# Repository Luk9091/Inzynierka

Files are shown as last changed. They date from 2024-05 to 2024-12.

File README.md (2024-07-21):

# Projekt Inżynierski
# Temat: Pojazdy autonomiczne z możliwością oceny aktualnej sytuacji na drodze

Opis:
Projekt zakłada zbudowanie autonomicznego pojazdu, który potrafiłby poruszać się po modelu miasta w sposób bezobsługowy. 
Układ rozpoznaje tor po którym się porusza. 
Samochód tworzy dwu-wymiarową mapę przestrzeni, a dla tak stworzonej mapy potrafi wyznaczyć optymalną trasę do punktu docelowego.

Powyższe repozytorium przedstawia *Projekt pracy inżynierskiej* będzie zbudowanie pojazdów autonomicznych, których zadaniem będzie poruszanie się po makiecie miasta.
Znajdowanie optymalnej trasy oraz możliwość rozwiązywania problemów dynamicznie pojawiających się problemów na wyznaczonej trasie.

# Uwagi do projektu!
Niezwykle ważne jest aby korzystać z określonej wersji FreeRTOS'a u mnie działa <u>**83da5fc95**</u>.

# Założenia budowy:
Projekt zakłada zbudowanie przynajmniej dwóch pojazdów. 
Każdy z pojazdów powinien spełniać poniższe założenia:
- [ ] Rozpoznawanie obrazu
    - [ ] Rozpoznawanie znaków
        - [ ] 1. Stop
        - [ ] 2. Zakręt
            - [ ] w prawo
            - [ ] w lewo
        - [ ] 3. Skrzyżowanie
        - [ ] 4. Ustąp pierwszeństwa
        - [ ] 5. Masz pierwszeństwo
- [ ] Tworzenie dynamicznej mapy 
    - [ ] Wyznaczanie trasy na mapie
    - [ ] Pomiar odległości
- [ ] Sterowanie silnikami
- [ ] Pomiary redundantne:
    - [ ] Pomiar temperatury
    - [ ] Pomiar azymutu
    - [ ] Pomiar wysokości nad poziomem morza
    - [ ] Pomiar przyspieszenia
    - [ ] Pomiar nachylenia

# Budowanie mapy
Mapa będzie przedstawiać, kwadratowe tile o ustalonych wymiarach `8b x 8b`

# Wymagania do zbudowania:
- C code lib:
    - RayLib

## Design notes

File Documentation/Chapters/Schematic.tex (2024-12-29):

\subsection{Opis układu}
    W rozdziale \ref{sec:building} opisano mechaniczną stronę projektu,
    natomiast poniżej przedstawiono elektroniczne aspekty pojazdu.
    Głównym odnośnikiem w tej sekcji jest schemat z rysunku \ref{schema:block}, prezentujący ogólny sposób połączenia całości.
    Moduły wybrane w tym układzie, zostały omówione we wstępie (rozdz. \ref{subsec:hardware}), dlatego też w tej sekcji skupiono się na zobrazowaniu relacji między poszczególnymi blokami.

    \subsection{Magistrala \texorpdfstring{$I^2C$}{I2C}}
        Protokół $I^2C$ (Inter-Integrated Circuit) jest szeregowym standardem komunikacyjnym między urządzeniem głównym (,,master'') a wieloma odbiornikami (,,slaves'').
        Transmisję rozpoczyna ,,master'', wysyłając adres podzespołu docelowego wraz z bitem $R/W$ ($Read / Write$), który informuje ,,slave'a'' czy ma odebrać, czy nadawać.
        Warstwę fizyczną realizują dwie linie Serial-Data (SDA) i Serial-Clock (SCL).
        Linia zegara odpowiada za synchronizację bitów, przekazywanych po ścieżce danych.
        Na rysunku \ref{fig:i2c_data_frame} przedstawiono przykładową ramkę tego protokołu.

        \begin{figure}[!ht]
            \centering
            
            \caption{Ramka protokołu $I^2C$}
            \label{fig:i2c_data_frame}
            Źródło: \href{https://en.wikipedia.org/wiki/I%C2%B2C}{en.wikipedia.org/wiki/$I^2C$}
        \end{figure}

        W tym projekcie, powyższy standard wykorzystywany jest do komunikacji z trzema rodzajami urządzeń:
        \begin{table}[!ht]
            \centering
            \caption{Lista urządzeń podłączonych za pomocą $I^2C$}
            \begin{tabular}{|c|c|c|c|}\hline
                Nazwa      & Identyfikator & Adres $I^2C$ & Liczba\\
                urządzenia &   układu      &(hexadecymalnie)& modłów\\\hline
                Akcelerometr & \centerY{2}{MPU6050} & \centerY{2}{0x68} & \centerY{2}{1} \\
                i żyroskop   &&&\\\hline
                Magnetometr & QMC5883L & 0x0D & 1 \\\hline
                ToF & VL53L0 & 0x29 & 3 \\\hline
            \end{tabular}
        \end{table}

        W przypadku każdego z układów adres domyślny ustalany jest przez producenta.
        Konsekwencją podłączenia kilku takich samych komponentów do magistrali, może być konflikt transmisji - błędy podczas odczytywania danych.
        Dlatego producenci czasem umożliwiają zmianę adresu urządzenia docelowego.
        Wymaga to jednak zastosowania dodatkowych linii $xShut$, pozwalających na sekwencyjne uruchamianie czujników, w celu nadania im nowego identyfikatora.
        Procedura ta została wykorzystana do połączenia modułów ToF.

    \subsection{Protokół \texorpdfstring{$SPI$}{SPI}}
        Trzy- lub cztero- przewodowy protokół transmisji szeregowej, pozwalający na szybkie przesyłanie dużej ilości danych.
        Bardzo często używany do komunikacji z pamięcią zewnętrzną lub innym procesorem.
        Dokładny opis tej magistrali znajduje się w dokumencie \citetitle{SPI} \cite{SPI}.
        W tym projekcie pamięć zewnętrzną $W25Q32JV$ podłączono do mikrokontrolera za pomocą czteroprzewodowej odmiany tego standardu.
        % \cite{SPI_memory}.

    \subsection{Mostek H i sterowanie silnikami}
        Sterowanie silnikami odbywa się poprzez specjalne układy, tak zwane mostki H, które pozwalają na przepływ znacznego prądu.
        Kontrolę każdego silnika zapewniają trzy przewody: \textit{enable, in~1, in~2}, a odpowiednie stany opisuje tabela poniżej (tab \ref{tab:motor_control_state}).

        \begin{table}[!ht]
            \centering
            \caption{Schemat sterowania silnikiem}
            \label{tab:motor_control_state}
            \begin{tabular}{|c|c|c|c|}\hline
                \multicolumn{3}{|c|}{Stan przewodu:} & \centerY{2}{Stan silnika} \\\cline{1-3}
                \textit{Enable} & \textit{In 1} & \textit{In 2} & \\\hline
                L & x & x & Stop\\\hline
                H & L & L & Stop\\\hline
                H & L & H & Obroty w prawo\\\hline
                H & H & L & Obroty w lewo\\\hline
                H & H & H & Stop\\\hline
            \end{tabular}
        \end{table}
        gdzie:
        \begin{itemize}
            \item x -- stan dowolny,
            \item L -- stan niski - zero logiczne,
            \item H -- stan wysoki - jedynka logiczna.
        \end{itemize}

        Jak widać obsługa napędu jest prostym zadaniem, a dodatkowo podłączając sygnał PWM do wejścia \textit{enable}, można regulować prędkość silnika.
        Co więcej, do obu motorów dołączone są enkodery, połączone z procesorem za pomocą czterech przewodów.
        Raspberry Pi Pico nie posiada sprzętowych liczników, jednak kontroler PWM pozwala na maskowanie głównego zegara zewnętrznymi sygnałami, na przykład zboczem sygnału z enkodera.
        Dzięki temu można zliczać impulsy, wysyłane przez te układy.
        Na wykresie poniżej (rys. \ref{plot:speed_in_duty}) przedstawiono zależność prędkości silnika od wypełnienia sterowania na linii \textit{enable}.

        \begin{figure}[!ht]
            \centering
            \begin{tikzpicture}
                \begin{axis}[
                    width = 0.6\textwidth,
                    grid = both,
                    grid style = dashed,
                    xlabel = Wypełnienie PWM {[\%]},
                    ylabel = Prędkość {$[\frac{mm}{s}]$},
                    legend pos = south east,
                    ytick = {20, 40, ..., 200}
                ]
                    \addplot table [x = duty, y = speedL, col sep = comma]{Measure/speed.csv};
                    % \addplot table [x = duty, y = speedR, col sep = comma]{Measure/speed.csv};
                    % \legend{Lewy silnik, Prawy silnik}
                \end{axis}
            \end{tikzpicture}
            \caption{Wykres prędkości silników w zależności od wypełnienia sygnału PWM}
            \label{plot:speed_in_duty}
            Pomiar przeprowadzony przy napięciu zasilania mostka $6V$ \\
            i stałej częstotliwości $f_{PWM} = 25kHz$
        \end{figure}

    % \subsection{Serwomechanizm}
    %     Na schemacie z rysunku \ref{schema:block} literą $S$ oznaczono serwomechanizm, kontrolujący przednią oś pojazdu.
    %     Sterowanie modułem odbywa się za pomocą kontroli wypełnienia sygnału w zakresie od $150\mu s$ do $950\mu s$, pracującego na częstotliwości $f_{PWM} = 50Hz$.

    % \subsection{Czujniki cofania}
    %     Oba czujniki zostały podłączone bezpośrednio do mikroprocesora.

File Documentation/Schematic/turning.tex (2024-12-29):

\begin{figure}[!ht]
    \centering
    \begin{tikzpicture}
        \draw
            (0, 0) node[draw, rectangle, rounded corners, fill = black, minimum width = 2cm, minimum height = 0.8cm, rotate = 30](frontL){}
            (0, -3) node[draw, rectangle, rounded corners, fill = black, minimum width = 2cm, minimum height = 0.8cm, rotate = 30](frontR){}

            (6, 0) node[draw, rectangle, rounded corners, fill = black, minimum width = 2cm, minimum height = 0.8cm](backL){}
            (6, -3) node[draw, rectangle, rounded corners, fill = black, minimum width = 2cm, minimum height = 0.8cm](backR){}

            (3, 0) node[above]{Zewnętrzna strona}
            (3,-3) node[below]{Wewnętrzna strona}
        ;

        \draw[Stealth-Stealth]
            (frontL) ++ (0, 1) --node[above]{$l$}++ (6, 0)
        ;
        \draw[dashed, gray]
            (frontL) --++(0, 1)
            (backL) --++(0, 1)
        ;

        \draw[color = red]
            (backL) -- ++ (0, -10) -- ++ (0, -1) coordinate(meet) --++ (0, -1)
            (frontL) -- (meet)
            (frontR) -- (meet)
        ;
        \draw
            (meet) ++ (0, 3) arc(90:127:3) node[above]{$\alpha$}
            (meet) ++ (0, 2) arc(90:147:1) node[above]{$\beta$}
        ;

        \draw[dotted]
            (backL) to[short, l=$\Delta r$] (backR)
            (backR) ++ (0, -2.5) node[right]{$r$}
        ;

        \draw[dashed]
            (frontL) ++ (0, 1) -- (0, -5)
            (0, -4) arc(90:180:-1)
            (0.5, -4.5) node[]{$\gamma$}
            (1.2, -4.25) node[rotate = -50]{$90 - \gamma$}
        ;
    \end{tikzpicture}
    \caption{Rysunek poglądowy skręcania}
    \label{draw:turning_car}
\end{figure}

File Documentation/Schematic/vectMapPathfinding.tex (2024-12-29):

\begin{figure}[!ht]
    \centering
    \begin{tikzpicture}
        \draw[]
            (0,  0) node[draw, circle, minimum width = 2cm, align = center](start){Nowa\\ścieżka}
            (-3, -2.5) node[draw, circle, minimum width = 2cm, align = center](instruction){Zmiana w\\instrukcje}
            (0, -6) node[draw, diamond, minimum width = 2cm, align = center](check){Czy występuje\\kolizja}
            (6, -6) node[minimum width = 2cm, align = center](noCollision){Powtarzaj dla wszystkich\\instrukcji i wektorów}
        ;

        \draw[-Stealth] (start) to[bend left] (instruction);
        \draw[-Stealth] (instruction) to[bend right] (check);
        \draw[-Stealth] (check) to[bend right] node[right]{Tak} (start);
        \draw[-Stealth] (check) to[bend right] node[below]{Nie} (noCollision);
        \draw[-Stealth] (noCollision) to[bend right] (check);
    \end{tikzpicture}
    \caption{Uproszczony algorytm do wyznaczania ścieżek na mapie wektorowej}
    \label{schematic:vectorMapPathfinding}
\end{figure}

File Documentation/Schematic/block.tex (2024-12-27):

    \useNormalLandscape
\section{Schemat elektroniczny}
    Na schemacie blokowym z rysunku \ref{schema:block} przedstawiono przepływ sygnałów sterujących wraz z połączeniem poszczególnych modułów.
\begin{figure}[!ht]
\centering
\vspace{1cm}
\begin{circuitikz}[fill = white]
    \draw[very thick]
        (0, 0) node[draw, rectangle, fill, minimum width = 4cm, minimum height = 4cm, align = center] (MCU) {Mikrokontroler\\\scriptsize{Raspberry PI Pico W}}

        (0, -5) node[draw, rectangle, fill, minimum width = 3cm, minimum height = 3cm, align = center] (HBridge){Mostek H}
        (HBridge.south) ++(1, 0) --++(0, -1) to[Telmech=M, n = LMotor] ++ (2, 0) --++ (0, 2) --++ (-2, 0)
        (HBridge.south) ++(-1, 0) --++(0, -1) to[Telmech=M,n = RMotor] ++ (-2, 0) --++ (0, 2) --++ (2, 0)

        (-10, 4) node[draw, rectangle, fill, minimum width = 2cm, minimum height = 2cm, align = center] (ToF1) {$\text{ToF}_1$}
        (-7, 4) node[draw, rectangle, fill, minimum width = 2cm, minimum height = 2cm, align = center] (ToF2) {$\text{ToF}_2$}
        (-4, 4) node[draw, rectangle, fill, minimum width = 2cm, minimum height = 2cm, align = center] (ToF3) {$\text{ToF}_3$}

        (-6, 0) node[draw, rectangle, fill, minimum width = 2cm, minimum height = 2cm, align = center] (MPU6050){MPU6050}
        (-6, -4) node[draw, rectangle, fill, minimum width = 2cm, minimum height = 2cm, align = center] (Magneto){Magnetometr}

        (6, -4) node[draw, rectangle, fill, minimum width = 2cm, minimum height = 2cm, align = center] (LIR){Czujnik\\cofania}
        (9, -4) node[draw, rectangle, fill, minimum width = 2cm, minimum height = 2cm, align = center] (RIR){Czujnik\\cofania}

        (6, 4) node[elmech=M, scale = 1.5](servo){S}
        (8, 0) node[draw, rectangle, fill, minimum width = 2cm, minimum height = 2cm, align = center] (memory) {Pamięć}
    ;

    \draw[]
        (MCU.east) to[bmultiwire = 4, a = SPI] (memory.west)
        (MCU.east) ++ (0, 1) to[short, i=PWM] ++ (4, 0) -| (servo.south)
        (MCU.east) ++ (0,-1) to[bmultiwire = 2] ++ (2, 0) --++ (0, -1) to[short, i<= Detect, -*]++ (2, 0) coordinate(IR_node)
            (IR_node)  to[multiwire=1] (LIR.north)
            (IR_node)  to[multiwire=1] ++ (3, 0)-| (RIR.north)

        (MCU.south) to[tmultiwire=6, i=\ ] (HBridge.north)

        (MCU.west) to[bmultiwire = 2, a = I2C, -*] ++ (-2, 0) coordinate(I2C)
        (I2C) -- (MPU6050.east)
        (I2C) |- (Magneto)

        (I2C) to[short, -*] ++ (0, 2) coordinate(I2C)
        (I2C) -- (ToF3.south)
        (I2C) to[short, -*]++ (-3, 0) coordinate(I2C) -- (ToF2.south)
        (I2C) -| (ToF1)

        (LMotor) to[crossing, i =\ ] ++ (0, 4) --++ (0, 0.5) to[bmultiwire, a = 2] ++ (-1, 0) --++ (0, 1)
        (RMotor) to[crossing, i =\ ] ++ (0, 4) --++ (0, 0.5) to[bmultiwire, l = 2] ++ ( 1, 0) --++ (0, 1)

        (ToF1.south) ++ (0.5, 0) -- ++ (0, -0.5)
            --++ (2, 0) to[crossing] ++ (1, 0)
            --++ (2, 0) to[crossing] ++ (1, 0)
            --++ (0, -1.25) to[tmultiwire, l = xShut, i<= \ ] ++ (1.5, 0)
        (ToF2.south) ++ (0.5, 0) to[short, -*] ++ (0, -0.5)
        (ToF3.south) ++ (0.5, 0) to[short, -*] ++ (0, -0.5)
    ;
\end{circuitikz}
\caption{Schemat blokowy przedstawiający przepływ sygnałów}
\label{schema:block}
\end{figure}
    \useportrait

\input{Chapters/Schematic.tex}

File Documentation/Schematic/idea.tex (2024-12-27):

    \useNormalLandscape
\section{Schemat ideowy}
\begin{figure}[!ht]
\centering
\vspace{1cm}
\begin{circuitikz}
    \draw
        % (0, -2) coordinate(GND_0)  node[right]{GND}

        (0,  0.0) coordinate(GPIO_0 ) node[right]{GPIO 0 }
        (0, -0.5) coordinate(GPIO_1 ) node[right]{GPIO 1 }
        (0, -1.0) coordinate(GND_0)   node[right]{GND}

        (0, -1.5) coordinate(GPIO_2 ) node[right]{GPIO 2 }
        (0, -2.0) coordinate(GPIO_3 ) node[right]{GPIO 3 }
        (0, -2.5) coordinate(GPIO_4 ) node[right]{GPIO 4 }
        (0, -3.0) coordinate(GPIO_5 ) node[right]{GPIO 5 }
        (0, -3.5) coordinate(GND_1)   node[right]{GND}

        (0, -4.0) coordinate(GPIO_6 ) node[right]{GPIO 6 }
        (0, -4.5) coordinate(GPIO_7 ) node[right]{GPIO 7 }
        (0, -5.0) coordinate(GPIO_8 ) node[right]{GPIO 8 }
        (0, -5.5) coordinate(GPIO_9 ) node[right]{GPIO 9 }
        (0, -6.0) coordinate(GND_2)   node[right]{GND}

        (0, -6.5) coordinate(GPIO_10) node[right]{GPIO 10}
        (0, -7.0) coordinate(GPIO_11) node[right]{GPIO 11}
        (0, -7.5) coordinate(GPIO_12) node[right]{GPIO 12}
        (0, -8.0) coordinate(GPIO_13) node[right]{GPIO 13}
        (0, -8.5) coordinate(GND_3)   node[right]{GND}

        (0, -9.0) coordinate(GPIO_14) node[right]{GPIO 14}
        (0, -9.5) coordinate(GPIO_15) node[right]{GPIO 15}

%  ##############################

        (5,  0.0) coordinate(VBUS)    node[left]{VBUS}
        (5, -0.5) coordinate(VSYS)    node[left]{VSYS}
        (5, -1.0) coordinate(GND_7)   node[left]{GND}

        (5, -1.5) coordinate(ADC)     node[left]{ADC REF}
        (5, -2.0) coordinate(3V3_EN)  node[left]{3V3 EN}
        (5, -2.5) coordinate(3V3)     node[left]{3V3}
        (5, -3.0) coordinate(GPIO_28) node[left]{GPIO 28}
        (5, -3.5) coordinate(GND_6)   node[left]{GND}

        (5, -4.0) coordinate(GPIO_27) node[left]{GPIO 27}
        (5, -4.5) coordinate(GPIO_26) node[left]{GPIO 26}
        (5, -5.0) coordinate(RUN)     node[left]{RUN}
        (5, -5.5) coordinate(GPIO_22) node[left]{GPIO 22}
        (5, -6.0) coordinate(GND_5)   node[left]{GND}

        (5, -6.5) coordinate(GPIO_21) node[left]{GPIO 21}
        (5, -7.0) coordinate(GPIO_20) node[left]{GPIO 20}
        (5, -7.5) coordinate(GPIO_19) node[left]{GPIO 19}
        (5, -8.0) coordinate(GPIO_18) node[left]{GPIO 18}
        (5, -8.5) coordinate(GND_4)   node[left]{GND}

        (5, -9.0) coordinate(GPIO_17) node[left]{GPIO 17}
        (5, -9.5) coordinate(GPIO_16) node[left]{GPIO 16}

        (0, 0.25) rectangle ++ (5, -10)
    ;
\end{circuitikz}
\end{figure}
    \useportrait

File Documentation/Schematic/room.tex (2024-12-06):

\begin{figure}
    \centering
    \begin{tikzpicture}[scale = 2]
        \draw
            (0, 0) rectangle (4.1, 2.7)
            (2, 1.7) --++ (2.1, 0)
            (2, 1.7) --++ (0, 1)
            (3.1, 0.2) --++(1, 0)
            (3.1, 0.2) --++(0,-0.2)
            
            (2.0, 1.5) node[draw, circle, minimum width = 0.5cm, fill = red]{}
            (3.1, 1.5) node[draw, circle, minimum width = 0.5cm, fill = red]{}
            (3.5, 1.0) node[draw, circle, minimum width = 0.5cm, fill = red]{}
        ;
        \draw[color=gray, dashed]
            (2.0, 1.5) -- (3.1, 1.5)
            (3.1, 1.5) arc(90:0:0.4)
        ;

        \draw[Stealth-Stealth] (2, 2) --node[above]{$2.0m$}++ (2.1, 0);
        \draw[Stealth-Stealth] (4.2, 1.7) --node[right]{$1.5m$}++ (0, -1.5);
        \draw[Stealth-Stealth] (3.1,-0.1) --node[below]{$1.0m$}++ (1, 0);
        \draw[Stealth-Stealth] (3.0, 0.2) --node[left]{$0.2m$}++ (0,-0.2);

    \end{tikzpicture}
    \caption{Schemat mapowanego pomieszczenia}
    \label{schematic:room}
\end{figure}

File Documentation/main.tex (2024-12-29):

\documentclass[12pt]{article}
\usepackage{anyfontsize}
\usepackage[a4paper, margin=2cm]{geometry}
\usepackage{polski}
\usepackage{tabto}
\usepackage{enumitem}
\usepackage{amsmath}
\usepackage{amssymb}
\usepackage{multirow}
\usepackage{multicol}
\usepackage{setspace}
\usepackage{listings}
\input{verticalPages.tex}

\setlength{\emergencystretch}{10pt}

\usepackage{tabularx}
\newcolumntype{C}{>{\centering\arraybackslash}X}
\newcolumntype{L}{>{\raggedleft\arraybackslash}X}
\newcolumntype{R}{>{\raggedright\arraybackslash}X}
\newcommand{\centerY}[2]{\multirow{#1}{*}{#2}}

\usepackage{wrapfig}
\usepackage{subcaption}

\usepackage{hyperref}
\hypersetup{
    colorlinks = true,
    urlcolor=blue,
    linkcolor= black,
    citecolor= blue
}

\usepackage{chngcntr}
\counterwithin{figure}{section}
\counterwithin{table}{section}
\numberwithin{equation}{section}

\usepackage{graphicx}
\graphicspath{{./Img/}}

\usepackage{csvsimple}
\usepackage{pgfplots}
\usepackage{pgfplotstable}
\pgfplotsset{compat= newest}

\usepackage{titlesec}
\titlelabel{\thetitle.\quad}
% \AddToHook{cmd/section/before}{\clearpage}

\usepackage[european, american currents, americanvoltages, RPvoltages, cute inductor]{circuitikz}
\usepackage{tikz}
\usetikzlibrary{shapes.geometric}
\ctikzset{
    logic ports=ieee,
    logic ports/scale=0.7,
}

\usepackage[polish]{babel}
\usepackage{csquotes}
\usepackage[sorting=none]{biblatex}
\bibliography{bibliography.bib}

\lstdefinestyle{asm}{
    belowcaptionskip=1\baselineskip,
    frame=L,
    xleftmargin=\parindent,
    showstringspaces=false,
    numbers=left,
    firstnumber=1,
    basicstyle=\footnotesize,
    basicstyle=\ttfamily,
    tabsize=4,
}

\usepackage{listings}
\lstset{
literate=%
    {ą}{{\k{a}}}1
    {Ą}{{\k{A}}}1
    {ć}{{\'c}}1
    {Ć}{{\'{C}}}1
    {ę}{{\k{e}}}1
    {Ę}{{\k{E}}}1
    {ł}{{\l{}}}1
    {Ł}{{\L{}}}1
    {ń}{{\'n}}1
    {Ń}{{\'N}}1
    {ó}{{\'o}}1
    {Ó}{{\'O}}1
    {ś}{{\'s}}1
    {Ś}{{\'S}}1
    {ż}{{\.z}}1
    {Ż}{{\.Z}}1
    {ź}{{\'z}}1
    {Ź}{{\'Z}}1
}

\title{
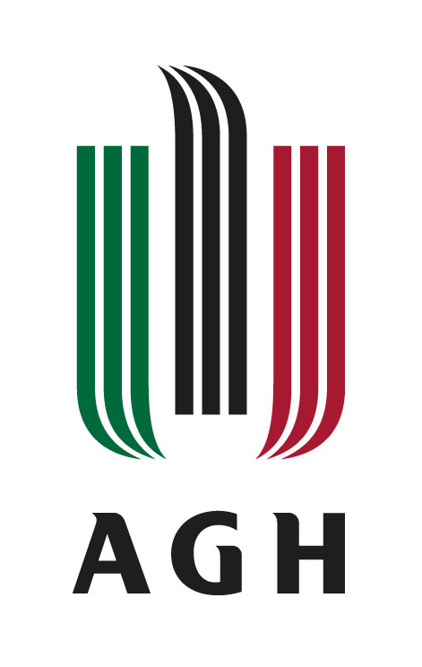
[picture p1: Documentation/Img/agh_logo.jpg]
    \\
    \textbf{Akademia Górniczo-Hutnicza w Krakowie}\\
    Wydział Informatyki, Elektroniki i  Telekomunikacji\\\vspace{2cm}
    \textbf{Praca inżynierska}\\
    Pojazd autonomiczny służący do pokonywania trasy z~przeszkodami\\\vspace{1cm}
    \small{An autonomous vehicle designed to navigate an obstacle course}
}
\author{
    \begin{tabularx}{\textwidth}{l l}
    Autor: &Łukasz Przystupa\\
    Kierunek studiów: & Elektronika\\
    Opiekun pracy: &dr inż. Agnieszka Dąbrowska-Boruch
    \end{tabularx}
}
\date{\vspace{2cm}\today}

\usepackage{titling}
\renewcommand\maketitlehooka{\null\mbox{}\vfill}
\renewcommand\maketitlehookd{\vfill\null}

\begin{document}
    \begin{titlepage}
        \maketitle
        \thispagestyle{empty}
        \newpage
        \
        \thispagestyle{empty}
    \end{titlepage}

    \pagenumbering{Roman}
        \include{shorts.tex}
        \tableofcontents
        \newpage
    \pagenumbering{arabic}
    % \input{Chapters/Abstract.tex}
    \include{Chapters/Introduction.tex}
    \include{Chapters/Building.tex}
    \include{Schematic/block.tex}
    \include{Chapters/Testing.tex}
    \include{Chapters/Issue.tex}
    \include{Chapters/Controll.tex}
    \include{Chapters/Map.tex}
\newpage
    \input{Chapters/Summary.tex}

    \vfill
    \begin{flushright}
        Łukasz Przystupa
    \end{flushright}

    \newpage
    \pagenumbering{gobble}
    \nocite{*}
    \printbibliography

    % \include{Schematic/idea}
    \listoffigures
    \listoftables
    % \lstlistoflistings

\end{document}

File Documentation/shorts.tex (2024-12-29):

\section*{Spis skrótów}
\addcontentsline{toc}{section}{Spis skrótów}
\begin{table*}[!ht]
    \begin{tabularx}{\textwidth}{|c|C|C|}\hline
        Skrót & Rozszerzenie\ & Opis\\\hline
        \centerY{2}{GPIO}       & \centerY{2}{General Purpose Input/Output} & Wyprowadzenia z układów scalonych do dowolnego wykorzystania\\\hline
        \centerY{2}{DIY}        & \centerY{2}{Do It Yourself} & Projekt do własnoręcznego wykonania\\\hline
        \centerY{2}{SSH}        & \centerY{2}{Secure Shell} & Protokół komunikacyjny, pozwalający na bezpieczne połączenie do serwera\\\hline
        \centerY{2}{HAL}        & \centerY{2}{Hardware Abstraction Layer} & Sposób porozumiewania się ze~sprzętem\\\hline
        \centerY{1}{RB Pi Pico} & \centerY{1}{Raspberry Pi Pico} & Mikrokontroler firmy Raspberry Pi\\\hline
        \centerY{3}{PWM}        & \centerY{3}{Pulse Wave Modulation} & Rodzaj modulacji cyfrowych pozwalający na regulację wypełnienia sygnału\\\hline
        \centerY{3}{ToF}        & \centerY{3}{Time of Flight} & Rodzaj czujników pomiaru odległości, polegający na pomiarze czasu przelotu wiązki światła\\\hline
        \centerY{2}{IR}         & \centerY{2}{Infrared} & Czujniki wykrywające promieniowanie podczerwone\\\hline
        \centerY{2}{CAD}        & \centerY{2}{Computer Aided Design} & Zestaw narzędzi do projektowania np.~modeli 3D\\\hline
        \centerY{3}{BMS}        & \centerY{3}{Battery Management System} & Układ elektroniczny, zabezpieczający akumulatory między innymi przed nadmiernym rozładowaniem\\\hline
        \centerY{4}{$I^2C$}     & \centerY{4}{Inter-Integrated Circuit} & Szeregowy protokół komunikacyjny, wykorzystywany do przekazywania danych między kilkoma czujnikami i~procesorem\\\hline
        \centerY{1}{$SDA$}      & \centerY{1}{Serial Data Line} & Linia danych w protokole $I^2C$\\\hline
        \centerY{1}{$SCL$}      & \centerY{1}{Serial Clock Line} & Linia zegara w protokole $I^2C$\\\hline
    \end{tabularx}
\end{table*}

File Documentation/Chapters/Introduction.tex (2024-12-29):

\section{Wstęp}
    Celem poniższej pracy jest skonstruowanie autonomicznego pojazdu, którego zadaniem będzie zbudowanie wirtualnej mapy terenu oraz samodzielne poruszanie się po nieznanym obszarze.
    Jednym z założeń projektu jest umożliwienie użytkownikowi kontroli nad pojazdem za pomocą dedykowanej aplikacji komputerowej.
    Dodatkowo, powyższa aplikacja będzie wyświetlać budowaną mapę w czasie rzeczywistym.
    Po wskazaniu punktu docelowego, zostanie zaproponowana optymalna trasa, po której pojazd będzie się poruszał.

    \subsection{Środowisko sprzętowe}
    \label{subsec:hardware}
        Współczesne pojazdy autonomiczne wyposażone są w jednostki obliczeniowe, które swoją konstrukcją przypominają pełnoprawne komputery z systemem operacyjnym.
        Ten projekt ma być modelem,  przedstawiającym działanie pojazdu autonomicznego, dlatego wykorzystanie pełnoprawnego komputera jest zbędne.

        \subsubsection{Mikrokontroler}
            Poniżej przedstawiono kilka najbardziej popularnym platform sprzętowych, które mogą stanowić bazę dla pojazdu.
            \begin{enumerate}
                \item Raspberry Pi -- komputer z systemem operacyjnym Linux, umożliwiający bezpośredni dostęp do modułów zewnętrznych z pomocą GPIO.
                Jest to najbardziej popularna platforma dla projektów DIY.
                Układ pozwala na niesamowitą elastyczność w pracy, między innymi na podłączenie się do układu za pośrednictwem SSH oraz pracę w języku Python.
                Jednak ze względu na swoją popularność, jest bardzo drogi i mało dostępny.
                Natomiast, jednym z założeń projektu jest działanie w czasie rzeczywistym, co przy wykorzystaniu systemu operacyjnego jest niemożliwe.
                \item Arduino -- najpopularniejsza platforma, której głównymi zaletami są: prostota framework'u oraz mnogość bibliotek dla każdego układu.
                Niestety, płytki te oparte są o 8-bitowe mikrokontrolery z rodziny AVR, co odbija się na ich prędkościach  (max 20MHz).
                Sam framework wykorzystywany jest na wielu różnych praformach, przez co w dłuższej perspektywie staje się nieintuicyjny.
                \item STM32 -- układy projektowane przez firmę STMicroelectronics. Są znacznie szybsze i~posiadają więcej pamięci od Arduino.
                Jednak ze względu na potrzebę wykorzystania biblioteki HAL, programowanie jest znacznie trudniejsze w porównaniu do innych układów.
                \item ESP32 -- 32-bitowy dwurdzeniowy procesor z wbudowanym modułem WiFi i Bluetooth.
                Jeden z najszybszych mikrokontrolerów dostępnych na rynku. Jest bardzo popularny w~projektach IoT (wytłumaczyć).
                Natywnie pracuje w systemie czasu rzeczywistego - FreeRTOS. Dzięki temu ma potencjał na bycie idealnym kandydatem do tego projektu.
                Jednak znikoma dokumentacja produktu sprawia, że praca z nim jest uciążliwa, przez co opracowanie optymalnego kodu jest znacząco utrudnione.
                \item Raspberry Pi Pico -- mikrokontroler od firmy Raspberry Pi, oparty na rdzeniach Cortex - tak samo jak STM32.
                Producent udostępnił wyjątkowo przystępny zestaw narzędzi programistycznych oraz przykładów użycia.
                Kolejną z zalet jest dobra dokumentacja tego procesora, która jest stale rozwijana.
                W 2022 roku, pojawiła się druga iteracja tej płytki Raspberry Pi Pico~W ze zintegrowanym modułem WiFi.
            \end{enumerate}
            Projekt jest możliwy do zrealizowania na wszystkich wymienionych powyżej platformach.
            Jednak ze względu na swoją przystępność, Raspberry Pi Pico jest najbardziej optymalnym wyborem.
            \begin{figure}[!ht]
                \centering
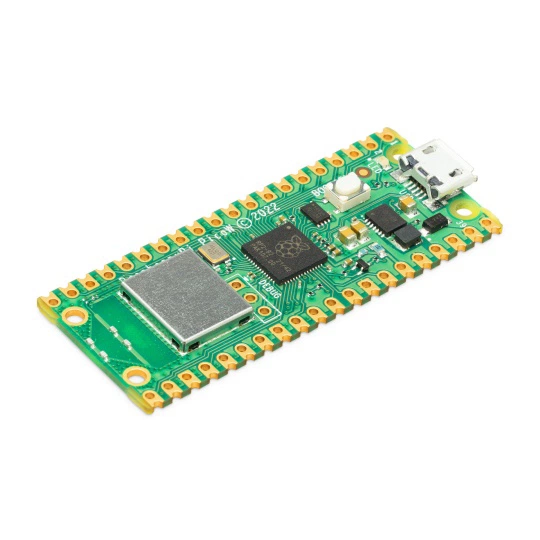
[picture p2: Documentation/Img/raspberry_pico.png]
                
                \caption{Raspberry Pi Pico}
                Źródło: \href{https://botland.com.pl/moduly-i-zestawy-do-raspberry-pi-pico/21574-raspberry-pi-pico-w-rp2040-arm-cortex-m0-cyw43439-wifi-5056561803173.html}{botland.com}

                % Źródło: https://botland.com.pl/silniki-dc-z-przekladnia-i-enkoderami/6287-silnik-z-przekladnia-sj01-120-1-6v-160rpm-enkoder-6959420910205.html
                % Źródło: https://botland.com.pl/serwa-typu-micro/20435-serwo-mg-90s-micro-180-stopni-metalowa-przekladnia-5904422380915.html
                \label{fig:raspberry_pico}
            \end{figure}

        \subsubsection{Sterowanie}
        \label{sec:engines}
            Podstawowym zadaniem pojazdów mechanicznych jest poruszanie się.
            Dlatego niezwykle istotne było wybranie odpowiedniego silnika napędowego.
            Na rynku konsumenckim istnieje jest wiele ich wariantów.
            Poniżej opisano możliwe rozwiązania oraz skrótowo omówiono ich wady i zalety:
            \begin{enumerate}
                \item Silniki krokowe -- niegdyś bardzo duże i drogie silniki, wymagające dodatkowych układów sterujących.
                Dziś jednak istnieją mniejsze, niskonapięciowe rozwiązania, które mogą być kontrolowaneZ bezpośrednio przez mikroprocesor.
                Niestety złożone sterowanie oraz niewielka prędkość maksymalna $v_{max} \approx 1 \frac{\text{obr.}}{s}$ sprawiają, że wykorzystanie ich w tym projekcie byłoby nieoptymalne.
                \item Serwomechanizmy $360^\circ$ -- silniki wraz z kontrolerem oraz przekładniami.
                Wbudowany układ pozwala na regulację prędkości z wysoką dokładnością.
                Nie ma jednak możliwości sprawdzenia, czy dwa moduły pracują z tą samą mocą.
                Może to prowadzić do wielu niepożądanych zachowań, jak na przykład trudności poruszaniem się w linii prostej.
                \item Serwomechanizmy $180^\circ$ -- ta odmiana pozwala na precyzyjne ustawienie pożądanego kąta.
                Układy te nie nadają się do napędzania pojazdów, gdyż ich zakres ruchu jest ograniczony do 180(stopni). Jednak, świetnie odnajdują się w sytuacjach, w których precyzja jest kluczowa.
                \item Silniki BLDC -- pozwalają osiągnąć bardzo wysokie prędkości.
                Niestety łączy się to z~niemałą ceną.
                Dodatkowo każdy silnik wymaga wyspecjalizowanych układu sterującego.
                \item Silniki DC -- urządzenia elektromechaniczne przetwarzające moc prądu stałego na energię mechaniczną.
                Pozwalają na regulację prędkości za pomocą PWM.
                Dodatkowo w sprzedaży dostępne są układy wyposazone w enkodery, pozwalające obliczyć średnią prędkość silnika, a w konsekwencji wyznaczyć różnicę w pracy między nimi.
            \end{enumerate}
            Układ napędowy został oparty na silnikach DC z zamontowanymi enkoderami.
            Dzięki czemu możliwy jest odczyt prędkości pojazdu, który pozwala na wprowadzanie korekty szybkości.
            Natomiast, do układu kierowniczego, najlepiej nada się serwomechanizm $180^\circ$, ze względu na możliwość precyzyjnego ustawienia kąta. Oba wybrane układy przedstawiono poniżej \ref{fig:engines}.
            \begin{figure}[!ht]
                \centering
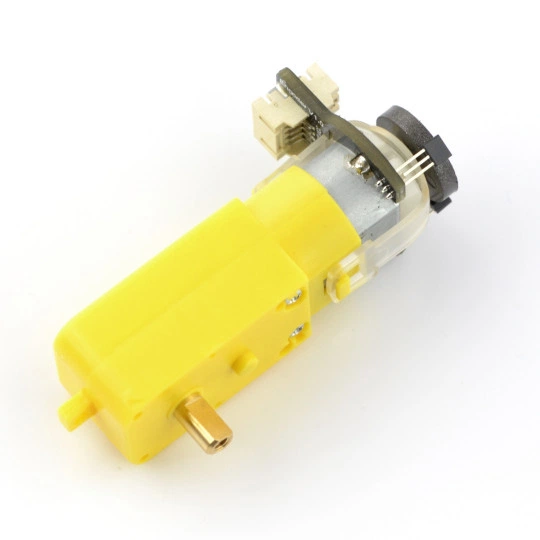
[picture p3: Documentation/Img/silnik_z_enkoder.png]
                
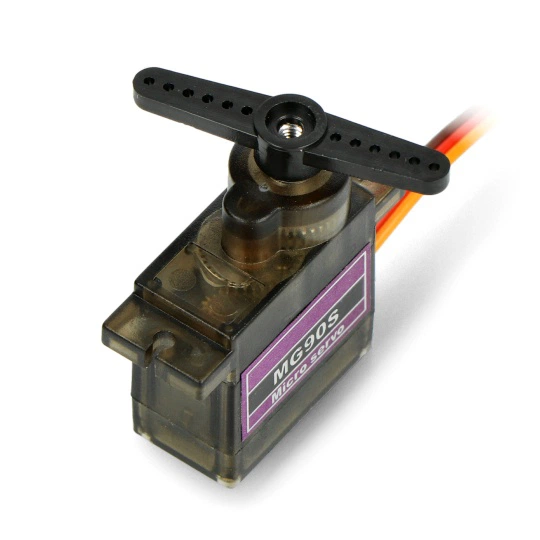
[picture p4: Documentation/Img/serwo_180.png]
                

                \caption{Silnik DC z enkoderem oraz serwomechanizmy $180^\circ$.}
                \footnotesize{Źródło: \href{https://botland.com.pl/}{botland.com}}
                % Źródło: https://botland.com.pl/silniki-dc-z-przekladnia-i-enkoderami/6287-silnik-z-przekladnia-sj01-120-1-6v-160rpm-enkoder-6959420910205.html
                % Źródło: https://botland.com.pl/serwa-typu-micro/20435-serwo-mg-90s-micro-180-stopni-metalowa-przekladnia-5904422380915.html
                \label{fig:engines}
            \end{figure}

        \subsubsection{Pomiar odległości}
            Praca pojazdów autonomicznych nie ogranicza się wyłącznie do sterowania silnikami.
            Urządzenia tego typu muszą być świadome swojego otoczenia.
            Zastosowanie odpowiednich czujników umożliwiających pomiar odległości jest niezbędne w celu zapewnienia bezkolizyjnej jazdy.
            % Autonomia pojazdu nie ogranicza się wyłącznie do sterowania silnikami.
            % Pojazd tego typu musi być świadomy swojego otoczenia.
            % Taką funkcjonalność mogą zapewnić czujniki służące do pomiaru odległości.
            % Ta funkcja wymaga wykorzystania czujników pozwalających na pomiar odległości.
            Poniżej przedstawiono listę różnych rodzajów czujników:
            \begin{enumerate}
                \item Czujniki ultradźwiękowe -- najpopularniejsze układy wykorzystywane do pomiaru odległości.
                Niewątpliwą zaletą jest prostota działania, jednak okupiona jest ona długim czasem wykonywania pomiarów.
                Co więcej uzyskane wartości obarczone są niepewnością, skutkującą znacznym odchyleniem od średniej.
                % Co więcej ich pomiary bywają niestabilne.
                \item Czujniki Time of Flight (ToF) -- wyspecjalizowane moduły o wysokiej dokładności, pozwalają na pomiary na znacznych odległościach.
                Zazwyczaj wymagają odpowiednich bibliotek dostarczonych przez producentów, co stanowi zarówno wadę jak i zaletę.
                Takie czujniki mogą pracować bardzo szybko jednak złożona, uniwersalna biblioteka spowalnia cały proces.
                \item Układy obiciowe IR -- obwody składające się z dwóch diod: emitera i odbiornika.
                Cechują się niewielkim zakresem pomiarowym (od $2cm$ do $20cm$) i znikomą dokładnością (pomiar zależy od koloru obiektu) oraz zauważalną strefą martwą.
                \item Lidar -- wyspecjalizowane układy, umożliwiające bardzo precyzyjny określenie odległości w pełnym zakresie $360^\circ$.
                Sprawia to, że jest jedną z najlepszych dostępnych opcji, jednak ceny takich układów są zaporowe.
                \item Radar -- niezwykle dokładne i kosztowne układy pomiarowe, pozwalające na nieporównywalną precyzję.
                Niestety ich rozmiar wymagany do tego projektu jest trudno dostępny na rynku konsumenckim.
                Co gorsza obowiązkowym staje się zastosowanie specjalnych procesorów sygnałowych, pozwalających na bieżąco przetwarzać dane z radarów.
            \end{enumerate}
            % Z wyżej przedstawionej listy, układami które sprawdzą się najlepiej w tym projekcie są czujniki typu ToF, zamontowane z przodu pojazdu.
            Z wyżej przedstawionej listy, w tym projekcie najlepiej sprawdzą się moduły ToF, zamontowane z przodu pojazdu.
            Dodatkowo ze względów bezpieczeństwa, z tyłu umieszczone zostały czujniki IR.
            Natomiast, nie są one wykorzystywane w charakterze urządzenia pomiarowego, tylko jako czujniki zbliżeniowe, umożliwiające wykrycie przeszkody i reakcję na niebezpieczeństwo.

    \subsection{Środowisko programistyczne}
        Następnym kluczowym wyborem jest środowisko programistyczne, w którym zostanie zbudowany projekt.
        % W ostatnich latach użytkownicy dostali bardzo dużo wolności w tej kwestii.
        W ostatnich latach powstało wiele narzędzi, pozwalających na dostosowanie całości do własnych potrzeb.
        Najpopularniejszymi narzędziami do programowania mikrokontrolerów są:
        \begin{enumerate}
            \item Eclipse -- kiedyś bardzo popularny program, posiadający olbrzymi zbiór rozszerzeń.
            Rozprowadzany na otwartej licencji, dlatego stanowi doskonałą bazę dla wielu bardziej zaawansowanych projektów.
            \item STM32 Cube -- środowisko przeznaczone głównie do pracy z modułami STM32, oparte na wyżej wymienionym Eclipse.
            \item Microchip Studio -- zbiór narzędzi wyspecjalizowanych do pracy z mikrokontrolerami z~rodziny AVR od firmy Microchip.
            \item Keil µVision -- program do programowania procesorów Cortex. Pomimo ograniczonej licencji jest bardzo popularny.
            \item Notepad++ -- bardziej zaawansowany notatnik, pozwalający na autouzupełnianie słów.
            Posiada też masę wtyczek, umożliwiających stworzenie z niego pełnoprawnego środowiska programistycznego, jednak w swojej pierwotnej wersji bardzo toporny w użyciu.
            \item Visual Studio Code (VS Code) -- uniwersalne narzędzie, mające ogrom dodatków, które dają możliwość przystosowania edytor w pełni pod własne wymagania.
            Sam program zbudowany jest na silniku przeglądarki internetowej, dzięki czemu może z powodzeniem zastąpić jej funkcje takie jak: przeglądarka PDF, a wbudowany tile menedżer pozwala układać całość w bardzo czytelny sposób.
        \end{enumerate}
        Projekt został, zbudowany z wykorzystaniem programu VS Code, ze względu na największą elastyczność oraz możliwość dostosowania go do własnych potrzeb.

    \subsection{Środowisko CAD}
        Zbudowanie pojazdu autonomicznego wymagało wymodelowania kilku niestandardowych części.
        W tym celu, zostało wykorzystane środowisko CAD, pozwalające na zaprojektowanie modelu 3D.
        Poniżej przedstawiono trzy najpopularniejsze programów do projektowania.
        \begin{enumerate}
            \item SolidWorks -- program stworzony przez firmę Dassault Systemes, który jest bardzo popularny w przemyśle.
            Pozwala na nieporównywalną precyzję a każda operacja wymaga zastanowienia przez co próg wejścia jest bardzo wysoki.
            \item Fusion 360 -- program stworzony przez firmę Autodesk, przeznaczony specjalnie do modelowania 3D.
            Posiada olbrzymie wsparcie dla drukarek 3D, a także dla obrabiarek CNC.
            Jest także niezwykle intuicyjny a próg wejścia jest bardzo niski.
            Jedyną wadą programu w wersji konsumenckiej, jest możliwość pracy wyłącznie w chmurze.
            \item FreeCAD -- darmowy program do projektowania modeli 3D, bardzo prosty w obsłudze, a~nauczenie się tego programu wymaga naprawdę niewielkiego wkładu pracy.
            Program jest stale rozwijany, a społeczność wokół niego ma możliwość rozbudowywania go o nowe funkcje.
            Niewątpliwą zaletą w porównaniu do innych programów jest możliwość uruchomienia go na każdym systemie operacyjnym.
        \end{enumerate}

        W projekcie został wykorzystany program FreeCAD, ze względu na swoją prostotę oraz możliwość uruchomienia na systemie Linux.

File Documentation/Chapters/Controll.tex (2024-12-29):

\section{Sterowanie pojazdem}
    Kierowanie pojazdem powinno odbywać się w sposób płynny i precyzyjny.
    W niniejszym rozdziale zostaną omówione algorytmy, odpowiedzialne za najbardziej podstawowe funkcje poruszania się, takie jak: jazda prosto, skręt oraz cofanie.

    \subsection{Jazda przez pewien odcinek}
    \label{subsec:jazda_przez_odcinek}
        Poprzednio (rozdz. \ref{sec:problemy_konstrukcyjne}) opisano problemy, jakie wystąpiły podczas budowy projektu.
        Ich rozwiązanie umożliwiło powtarzalność manewrów.
        Jednak dla precyzyjnego sterowania informacja o~tym, że pojazd porusza się po linii jest niewystarczająca.
        Obowiązkowym staje się poznanie odległości jaka została pokonana.

        Dystans przejechany przez samochód od momentu startu, możemy dość dokładnie obliczyć korzystając ze wzoru \eqref{eq:pulseToDistance}.
        \begin{gather}
            s = \frac{pulse \cdot 2\pi R}{N}
            \label{eq:pulseToDistance}
        \end{gather}
        gdzie:
        \begin{itemize}
            \item $s$ -- odległość pokonana,
            \item $pulse$ -- liczba impulsów z enkodera,
            \item $R$ -- promień koła,
            \item $N$ -- liczba impulsów na obrót.
        \end{itemize}

        Przekształcenie tego równania, pozwala na wyznaczenie ilości impulsów, które muszą być zliczone na danym dystansie.
        % Równanie to można także przekształcić w drugą stronę, aby wyznaczyć ile impulsów enkodera musi zostać zliczonych przez procesor, aby pojazd pokonał zadaną odległość.
        \begin{gather}
            \text{pulse} = \frac{s \cdot N}{2\pi R}
            \label{eq:distanceToPulse}
        \end{gather}

        Dla zbudowanego modelu promień koła jest równy $R = 25 mm$, a liczba impulsów zgodnie z dokumentacją to $N = 1920$.
        A więc dokładność pomiaru odległości wynosi około:
        \begin{gather}
            \Delta s \approx \pm0.1mm
        \end{gather}

        Wykorzystując formułę \eqref{eq:distanceToPulse}, procesor jest w stanie zatrzymać silniki, po przejechaniu określonej drogi.

    \subsection{Wyznaczanie zakrętów}
    \label{subsubsec:minamalny_promien}
        Opracowanie idealnie prostej trasy dla pojazdów nie zawsze jest możliwe.
        W trakcie jazdy samochód będzie skręcał wielokrotnie w każdym kierunku.
        Przedstawiony model posiada dwie osie, przez co nieosiągalne jest wykonanie tego manewru w miejscu.
        Natomiast może swobodnie poruszać się po okręgu o minimalnym promieniu.
        W tej sekcji zostanie opisany sposób jego wyznaczania w funkcji od kąta skrętu kół.

\newpage
        % \subsubsection{Minimalny promień skrętu}
            Wykorzystując rysunek \ref{draw:turning_car} oraz zależność \eqref{eq:turning_radius}, można obliczyć promień skrętu.
            Po podstawieniu wartości do wzoru, otrzymujemy:
            \begin{gather}
                r(\gamma = 90 \pm 30^\circ) = \left|\frac{155}{\tan(\pm 30^\circ)}\right| \approx 270mm
                \label{eq:theoretical_radius}
            \end{gather}

            Obliczoną wartość należy skonfrontować z rzeczywistością.
            W tym celu zaprezentowano inną metodę wyznaczenia tego samego promienia.
            Równanie \eqref{eq:turning_arc} pozwala na poznanie omawianego parametru na podstawie zakreślonego kąta i długości łuku.
            \begin{gather}
                s = 2\pi (r(\gamma) + \Delta r) \cdot \frac{\alpha}{360}
                \label{eq:turning_arc}
                % \\
                % \alpha = \frac{2\pi (r(\gamma + \Delta r))}{s \cdot 360}
            \end{gather}
            gdzie:
            \begin{itemize}
                \item $s$ -- długość łuku,
                \item $r(\gamma)$ -- promień skrętu,
                \item $\Delta r$ -- odległość między kołami,
                \item $\alpha$ -- zakreślony kąt.
            \end{itemize}

            Przekształcając powyższą zależność uzyskujemy:
            \begin{gather}
                r(\gamma) = \frac{s}{2\pi \cdot \frac{\alpha}{360}} - \Delta r
                \label{eq:turning_radius_with_arc}
            \end{gather}

            Odległość pokonana przez samochód jest dokładnie mierzona przez enkodery, a zakreślony kąt został wyznaczony przez wcześniej skalibrowany akcelerometr.
            Z tego względu można uznać, że obie wartości są precyzyjne.

            Przykładowo, dla ustawionego maksymalnego kąta skrętu kół $\gamma = (90 + 30)^\circ$ oraz długości łuku $s = 500mm$, zakreślony kąt wyniósł $\alpha = 60.0^\circ$.
            Podstawiając podane wyniki do równania \eqref{eq:turning_radius_with_arc}, otrzymujemy:
            \begin{gather}
                r = \frac{500mm}{2\pi \cdot \frac{60}{360}} - 125mm \approx 350mm
            \end{gather}

            Teoretyczny minimalny promień skrętu wychodzący z obliczeń \eqref{eq:theoretical_radius}, jest znacząco mniejszy od zmierzonego.
            Wynika to z nieidealności konstrukcji oraz zastosowania ,,względnie słabej jakości'' serwomechanizmu,
            co ogranicza maksymalny zakres skrętu do $\pm 24^\circ$.
            \begin{gather}
                r(\gamma = 90 + 24^\circ) = \left|\frac{155}{\tan(+ 24^\circ)}\right| \approx 350mm
            \end{gather}

            Jednak po uwzględnieniu zależności z sekcji \ref{subsec:nierownomiernosc_skretu} okazuje się, że różnica między teoretycznym a obliczonym kątem skrętu kół wynosi dokładnie wartość offsetu ($-6^\circ$).
            Dlatego też ograniczenie skrętu kół do $\pm 24^\circ$ nie jest potrzebne.
            W późniejszych obliczeniach kąt skrętu kół brany pod uwagę będzie w zakresie $\pm 30^\circ$.

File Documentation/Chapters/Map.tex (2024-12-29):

\section{Mapa i orientacja przestrzenna}
    Jednym z założeń projektu było napisanie dedykowanej aplikacji graficznej do sterowania pojazdem oraz prezentacji mapy.
    Na rysunku \ref{fig:app} przedstawiono interfejs tego programu, który składa z trzech części:
    \begin{figure}[!ht]
        \centering
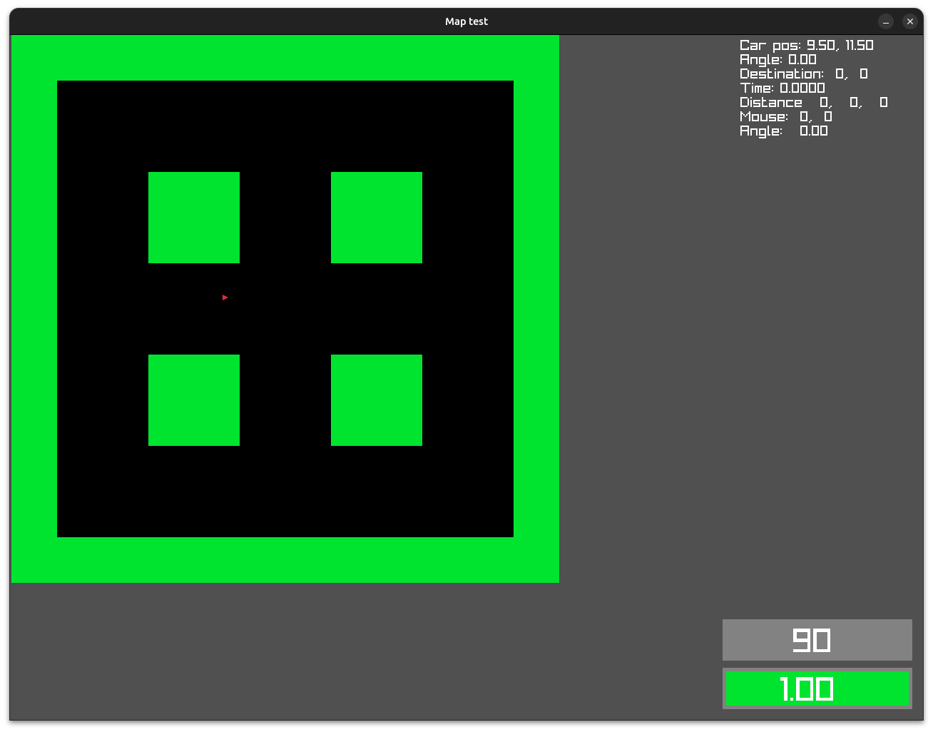
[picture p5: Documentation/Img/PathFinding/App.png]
        
        \caption{Interfejs aplikacji}
        \label{fig:app}
    \end{figure}
    \begin{enumerate}
        \item Mapa -- reprezentująca zbadany obszar oraz obecną pozycję pojazdu.
        \item Informacje -- w prawym górnym rogu wyświetlane są dodatkowe komunikaty, takie jak aktualne współrzędne samochodu, czy myszy.
        \item Ślizgacze -- w prawym dolnym rogu znajdują się dwa ślizgacze, górny umożliwia ustawienie kąta skrętu kół, a dolny pozwala na regulację prędkości pojazdu.
    \end{enumerate}

    \subsection{Wyszukiwanie ścieżek}
        W zamyśle program ma za zadanie jedynie wyświetlać mapę zbudowaną przez samochód, natomiast wszelkie obliczenia powinny zostać wykonane przez mikrokontroler.
        Jednak ze względu na dosyć skomplikowane przetwarzanie uzyskanych danych w celach testowych, to aplikacja posiada implementację przedstawionych algorytmów.

        Aby wytyczyć trasę, po której będzie poruszał się pojazd na narysowanej przestrzeni, należy wskazać punkt docelowy.
        W chwili kliknięcia rozpoczyna się złożony proces, który można podzielić na kilka podpunktów:
        \begin{enumerate}
            \item wyszukanie połączenia między dwoma miejscami,
            \item zamiana listy punktów na instrukcje,
            \item wygładzenie zakrętów.
        \end{enumerate}
        Wszystkie te elementy muszą działać niezawodnie, ponieważ błąd na którymkolwiek etapie, może mieć katastrofalne skutki.

        \subsubsection{Algorytm odnajdowania drogi}
        \label{subsec:algorytm_odnajdowania_ścieżek}
            Wyznaczanie optymalnej ścieżki, od wielu lat jest powszechnym problemem w informatyce i~robotyce.
            Istnieje mnóstwo artykułów, skupiających się na tej tematyce, a także ogrom gotowych rozwiązań.
            Do najpopularniejszych należą:
            \begin{itemize}
                \item algorytm A* (A star),
                \item algorytm Dijkstry,
                \item algorytm Bellmana-Forda.
            \end{itemize}

            Poniżej zaprezentowano wyniki pracy \citetitle{AnalizaAlgorytmówŚcieżek} \cite{AnalizaAlgorytmówŚcieżek}.
            \begin{figure}[!ht]
                \centering
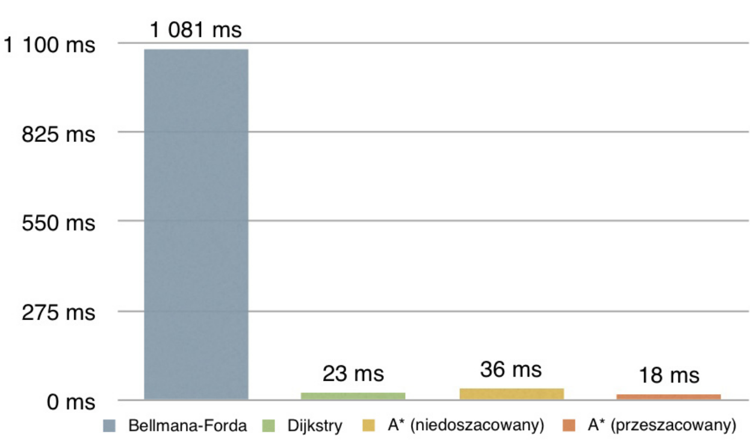
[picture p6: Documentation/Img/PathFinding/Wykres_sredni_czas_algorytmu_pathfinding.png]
                
                \caption{Wykres porównania średniego czasu wykonania algorytmów}
                Źródło:\cite{AnalizaAlgorytmówŚcieżek} \citetitle{AnalizaAlgorytmówŚcieżek}
                \label{fig:PathFindingTime}
            \end{figure}
            \begin{figure}[!ht]
                \centering
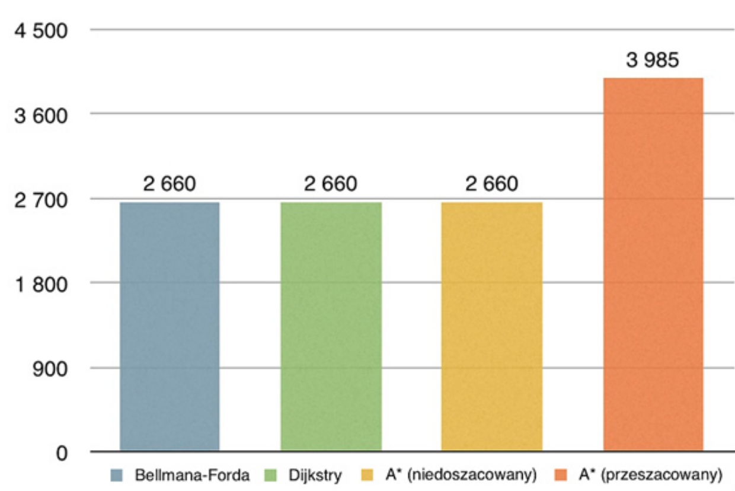
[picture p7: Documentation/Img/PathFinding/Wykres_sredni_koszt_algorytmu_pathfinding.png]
                
                \caption{Wykres porównania średniego kosztu znalezionych ścieżek}
                Źródło:\cite{AnalizaAlgorytmówŚcieżek} \citetitle{AnalizaAlgorytmówŚcieżek}
                \label{fig:PathFindingCost}
            \end{figure}

\newpage
            Na podstawie przedstawionego artykułu można wywnioskować, że najlepsze rozwiązanie to algorytm Dijkstry.
            Jego złożoność stanowi dodatkowy czynnik potwierdzający powyższe stwierdzenie.
            Jest on stosunkowo prosty w implementacji, a co więcej posiada niski koszt obliczeniowy.
            Dzięki temu wydaje się trafnym wyborem dla zastosowań w układach embedded.

    \subsection{Wygładzanie ścieżek}
    \label{subsec:wygładzanie_ścieżek}
        Rysunek \ref{fig:pathfinding_dikstra} prezentuje przykładową drogę, wyznaczoną przez algorytm Dijkstry,
        który zwraca najkrótsze połączenie między dwoma punkami, będące prostą.
        Jednak ze względu na ograniczenia konstrukcyjne wyrysowana trasa jest niemożliwa do pokonania przez robota.

        \begin{figure}[!ht]
            \centering
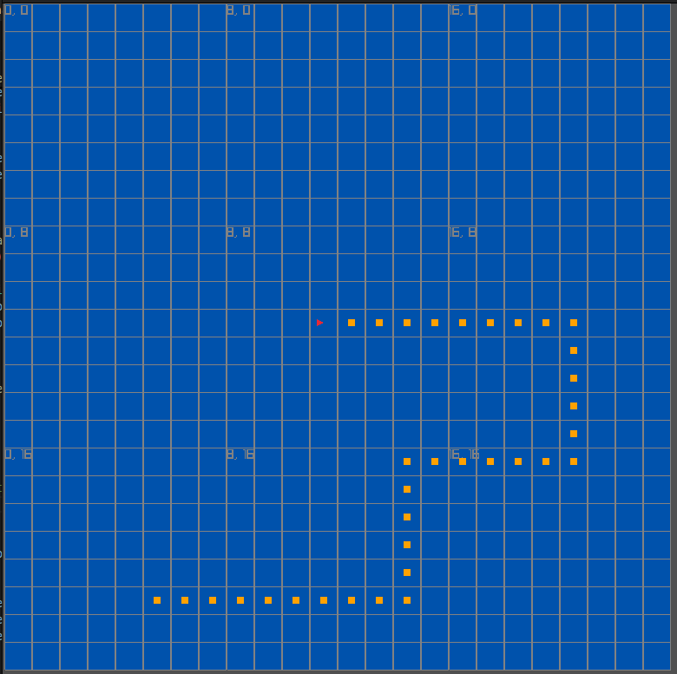
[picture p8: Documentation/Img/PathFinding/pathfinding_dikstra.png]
            
            \caption{Przykładowa ścieżka wyznaczona przez algorytm Dijkstry}
            \label{fig:pathfinding_dikstra}
        \end{figure}

        Zbudowany pojazd posiada tylko jedną oś skrętną, więc nie jest w stanie obrócić się w miejscu.
        Koniecznym jest zastosowanie algorytmu wygładzania.
        W artykule \citetitle{Simple_PathSmoothing} \cite{Simple_PathSmoothing} przedstawiona jest najprostsza możliwa metoda zaokrąglania krawędzi.
        Ów algorytm zakłada zapisywanie mapy w postaci listy punktów o niecałkowitych współrzędnych.
        Dzięki temu możliwe jest przesunięcie środka pojedynczej kratki w kierunku łuku skrętu.

        \begin{figure}[!ht]
            \centering
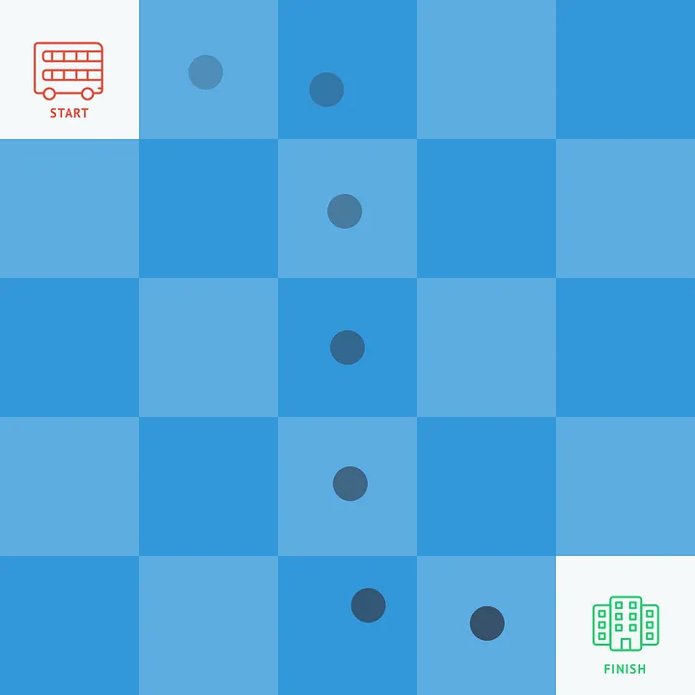
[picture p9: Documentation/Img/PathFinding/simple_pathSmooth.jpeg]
            
            \caption{Przykład wygładzania ścieżki na podstawie artykułu}
            \citetitle{Simple_PathSmoothing} \cite{Simple_PathSmoothing}
            \label{fig:simple_pathSmooth}
        \end{figure}

        Opisane rozwiązanie cechuje się niewielkim skomplikowaniem, jednak
        brak możliwości kontroli procesu, a także pocięcie drogi na pojedyncze punkty, między którymi pojazd będzie zatrzymywał się i ponownie ruszał, stanowią olbrzymi minus.
        Dodatkowo pojawia się problem przechowywania mapy w pamięci (sytuacja ta została dokładniej omówiona w rozdziale \ref{subsec:przechowywanie_mapy}).
        W związku z powyższym autor zdecydował się na użycie bardziej skomplikowanego algorytmu.

        Alternatywne metody wygładzenia ścieżek zostały ujęte w dokumentach: \citetitle{Compare_PathSmoothing} \cite{Compare_PathSmoothing} oraz \citetitle{Compare_PathSmoothing2} \cite{Compare_PathSmoothing2}.
        Obie prace przybliżają i~porównują różne sposoby dostosowywania trasy do umiejętności robota.
        Na rysunku \ref{fig:smoothingPath_res} przedstawiono ich wyniki:
        \begin{figure}[!ht]
            \centering
            \begin{minipage}{0.49\textwidth}
                \centering
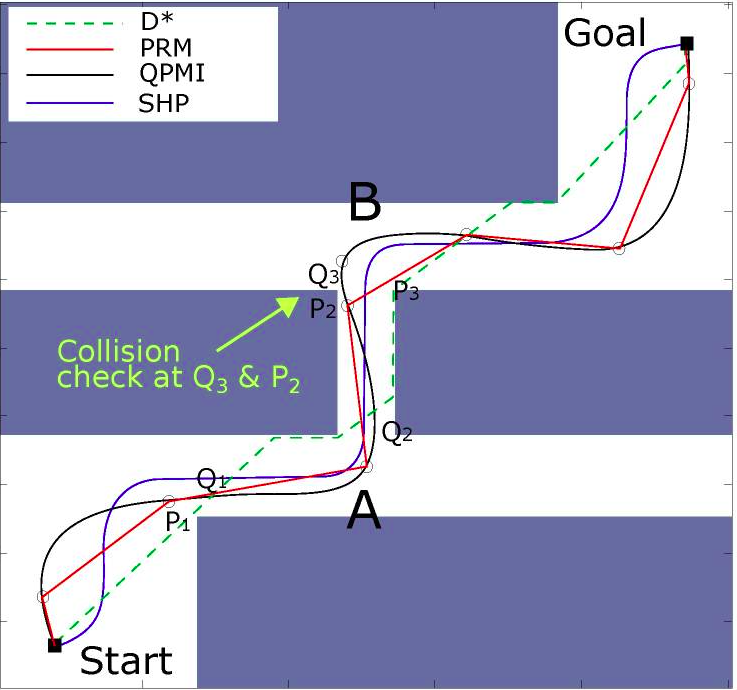
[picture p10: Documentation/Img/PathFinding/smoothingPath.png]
                
                Źródło: \cite{Compare_PathSmoothing} \citetitle{Compare_PathSmoothing}
            \end{minipage}
            \begin{minipage}{0.49\textwidth}
                \centering
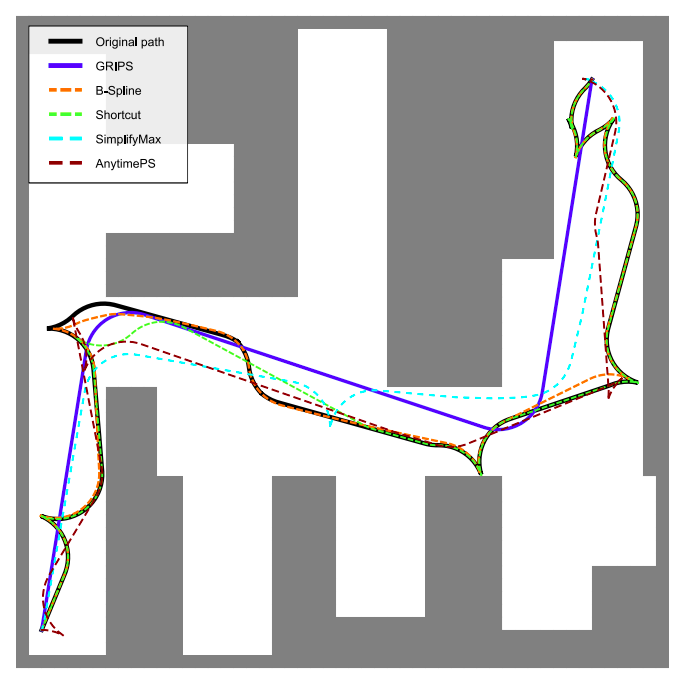
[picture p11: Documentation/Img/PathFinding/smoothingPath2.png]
                
                Źródło: \cite{Compare_PathSmoothing2} \citetitle{Compare_PathSmoothing2}
                \vspace{0.5cm}
            \end{minipage}
            \caption{Przedstawienie tras wygładzonych przez różne algorytmy}
            \label{fig:smoothingPath_res}
        \end{figure}

\newpage
        Ostatecznie spośród wszystkich wymienionych w artykułach metod został wybrany algorytm krzywych Dublina, ze względu na łatwą implementację oraz możliwość dostosowywania promienia skrętu.

\newpage
        \subsubsection{Opis algorytmu krzywych Dublina}
            Mechanizm wygładzania ścieżek za pomocą krzywych Dublina jest przeznaczony dla pojazdów o ograniczonej sterowności, przykładowo dla samochodów z tylko jedną osią skrętną.
            \begin{figure}[!ht]
                \centering
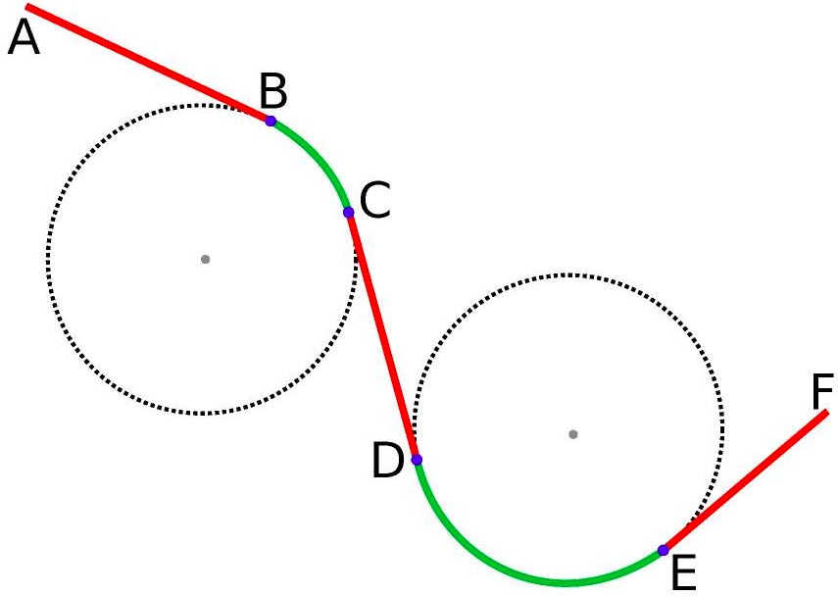
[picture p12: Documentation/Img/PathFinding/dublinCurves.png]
                
                \caption{Schemat trasy z okręgami o minimalnych promieniach}
                \label{fig:dublinCurves}
                Źródło: \cite{Compare_PathSmoothing} \citetitle{Compare_PathSmoothing}
            \end{figure}

        \begin{wrapfigure}[3]{R}{0.33\textwidth}
            \centering
            \vspace{-1cm}
            \begin{tikzpicture}
                \draw
                    (0,  0.0) node[draw, circle, minimum width = 0.5cm, align=center](A){1}
                    (0, -1.5) node[draw, circle, minimum width = 0.5cm, align=center](B){2}
                    (0, -3.0) node[draw, circle, minimum width = 0.5cm, align=center](C){3}
                    (0, -4.5) node[draw, circle, minimum width = 0.5cm, align=center](D){4}
                    (0, -6.0) node[draw, circle, minimum width = 0.5cm, align=center](E){5}
                    (0, -7.5) node[draw, circle, minimum width = 0.5cm, align=center](F){6}
                ;
                \draw[-Stealth] (A) -- (B);
                \draw[-Stealth] (B) -- (C);
                \draw[-Stealth] (C) -- (D);
                \draw[-Stealth] (D) -- (E);
                \draw[-Stealth] (E) -- (F);
                \draw[-Stealth] (F) to[bend right] (B);

            \end{tikzpicture}
            \caption{Implementacja algorytmu krzywych Dublina zastosowana w projekcie}
        \end{wrapfigure}

        Poniżej przedstawiono implementację algorytmu krzywych Dublina zastosowanego w projekcie.
        Opisana wersja jest nieoptymalną modyfikacją oryginału.

        \vspace{0.25cm}
        \begin{minipage}[l]{0.6\textwidth}
            \begin{enumerate}
                \item Zamiana punktów ścieżki na listę prostych o współrzędnych początkowych i końcowych.
                \item Ustalenie miejsca przecięcia się dwóch kolejnych linii.
                \item Wyznaczenie dwusiecznej kąta, tworzonego przez obie proste w punkcie przecięcia.
                \item Określenie kierunku, w którym samochód będzie poruszał się po zakręcie.
                \item Znalezienie na dwusiecznej środka okręgu, znajdującego się w przeciwnym kierunku do ruchu pojazdu.
                \item Obliczenie punktów styczności okręgu i obu prostych, które stanowią początek i koniec łuku.
            \end{enumerate}
        \end{minipage}
        \vspace{0.25cm}

        Pierwotne założenia mówią, że nie należy łączyć dwóch prostych łukiem, a zawsze o ile jest to możliwe ścieżka powinna zaczynać się i kończyć półokręgiem.
        Jednak w tym projekcie dużo łatwiej jest wyznaczyć łuk wiążący dwie proste, niż trzymać się optymalnej wersji algorytmu.
        Na rysunku \ref{fig:path_dublin} zaprezentowano rezultat wygładzania trasy.

        \begin{figure}[!ht]
            \centering
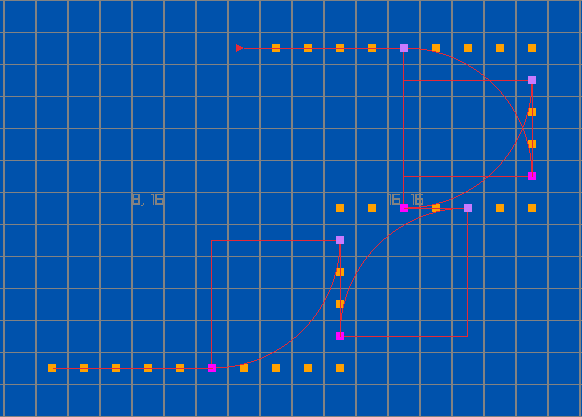
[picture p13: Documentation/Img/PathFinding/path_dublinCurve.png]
            
            \caption{Wyznaczona trasa z wygładzeniem}
            \label{fig:path_dublin}
        \end{figure}

    \subsection{Przechowywanie mapy}
    \label{subsec:przechowywanie_mapy}
        Przechowywanie mapy jest niezwykle złożonym zagadnieniem.
        W zależności od zastosowania oraz platformy, na której pracujemy, mogą istnieć różne sposoby jej przedstawienia.
        Zapisana na komputerze o teoretycznie nieograniczonej dostępnej pamięci, może być bardzo dokładna.
        Natomiast ten sam obraz analizowany przez mikrokontroler o niewielkich zasobach, musi zawierać uproszczenia.

        \subsubsection{Mapa jako tablica ścian}
            W wielu projektach mapa przechowywana jest w postaci dwuwymiarowej tablicy, w której poszczególne komórki odpowiadają określonym polom w labiryncie.
            Każda z nich zawiera informacje, w jakim kierunku można się poruszać.
            Przykład takiej budowy przedstawia artykuł \citetitle{maze_storage}\cite{maze_storage}.
            Na rysunku \ref{fig:mazeCellStorage} zilustrowano proponowane rozwiązanie.

            \begin{figure}[!ht]
                \centering
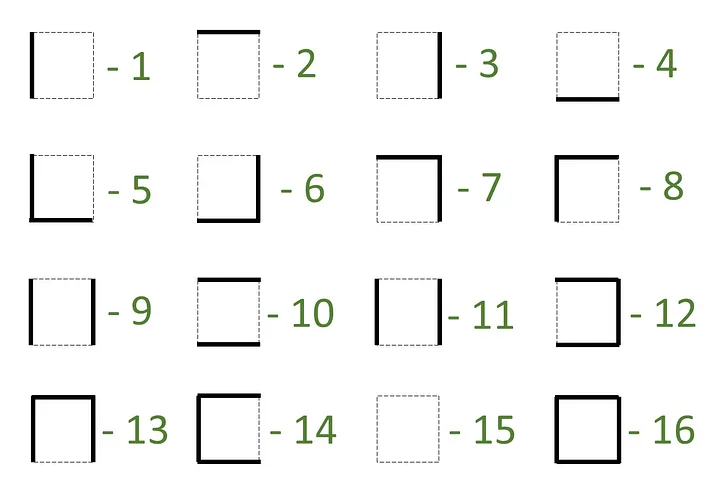
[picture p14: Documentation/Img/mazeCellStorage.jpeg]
                
                \caption{Przechowywanie komórek labiryntu z informacją o możliwości ruchu}
                Źródło: \citetitle{maze_storage}\cite{maze_storage}
                \label{fig:mazeCellStorage}
            \end{figure}

            Metoda ta jest bardzo skuteczna, kiedy znane są dokładne wymiary każdej części badanego obszaru,
            jednak przechowywanie mapy otwartej przestrzeni w podany sposób jest nieefektywne.
            Przykładowo, jeśli z kwadratu $A$ (patrz rys. \ref{fig:dim_issue}), nie da się jechać prosto to może oznaczać zarówno, że w miejscu połączenia z komórką $B$ jest ściana, jak i to, że pole $B$ jest całkowicie nieprzejezdne.
            W labiryncie, gdzie znaczenie mają krawędzie, prezentowane rozwiązanie jest optymalne.
            Jednak jeśli nie jesteśmy w stanie powiedzieć, czy wykrywamy cienką ściankę, czy też dużą przeszkodę, wtedy tracimy jednoznaczność.

            \begin{figure}[!ht]
                \centering
                \begin{tikzpicture}
                    \draw
                        (0, 0) -- (1, 0) -- (1, 1) -- (0, 1)
                        (0.5, 0.5) node{A}
                        (1, 0) rectangle (2, 1)
                        (1.5, 0.5) node[]{B}
                    ;
                \end{tikzpicture}
                \caption{Przykład niejednoznaczności wymiarów}
                \label{fig:dim_issue}
            \end{figure}

            Kolejną wadą takiej organizacji danych jest rozmiar pojedynczej komórki oraz czas potrzebny na przeanalizowanie wszystkich dostępnych opcji.
            Każdy kwadrat składa się z 4 bitów,
            co więcej łącząc poszczególne kratki ze sobą, okazuje się, że niektóre bity są nadmiarowe.
            Rozważmy sytuację: jeśli z punktu $A$ (rysunek \ref{fig:bit_issue}) nie możemy jechać do góry, to też, z punktu $C$ nie będzie możliwe przemieszczenie się w dół.
            Informacja dotycząca lokalizacji przeszkód musi zostać zapisana dla każdej komórki osobno.
            \begin{figure}[!ht]
                \centering
                \begin{tikzpicture}
                    \draw
                        (0, 0) -- (1, 0)
                        (1, 0) -- (2, 0) -- (2, 1) -- (1, 1)

                        (0.5, 0.5) node{A}
                        (0.5, 1.5) node{C}
                        (1.5, 0.5) node{D}
                    ;
                    \draw[dashed]
                        (0, 1) rectangle (1, 2)
                    ;
                    \draw[ultra thick, red]
                        (0, 1) -- (1, 1)
                    ;
                \end{tikzpicture}
                \caption{Przykład nadmiarowych informacji}
                \label{fig:bit_issue}
            \end{figure}\\
            Analogiczny problem występuje kiedy trasa jest przejezdna (połączenie między~$A$~i~$D$).

            Podsumowując, powyższa metoda przechowywania mapy jest użyteczna jedynie w przypadku labiryntów o jasno określonych zasadach.
            To rozwiązanie nie sprawdzi się do reprezentacji otwartej przestrzeni.
            Posiada zbyt wiele wad, aby można było próbować ją zastosować w~rzeczywistości.

        \subsubsection{Mapy wektorowe}
            Innym podejściem jest wykorzystanie wektorów.
            W takiej sytuacji teren rozważamy jako listę prostych figur geometrycznych, a nie jako zbiór komórek.
            Zostało to szczegółowo opisane w~artykule \citetitle{vector_map}\cite{vector_map}.

            \begin{figure}[!ht]
                \centering
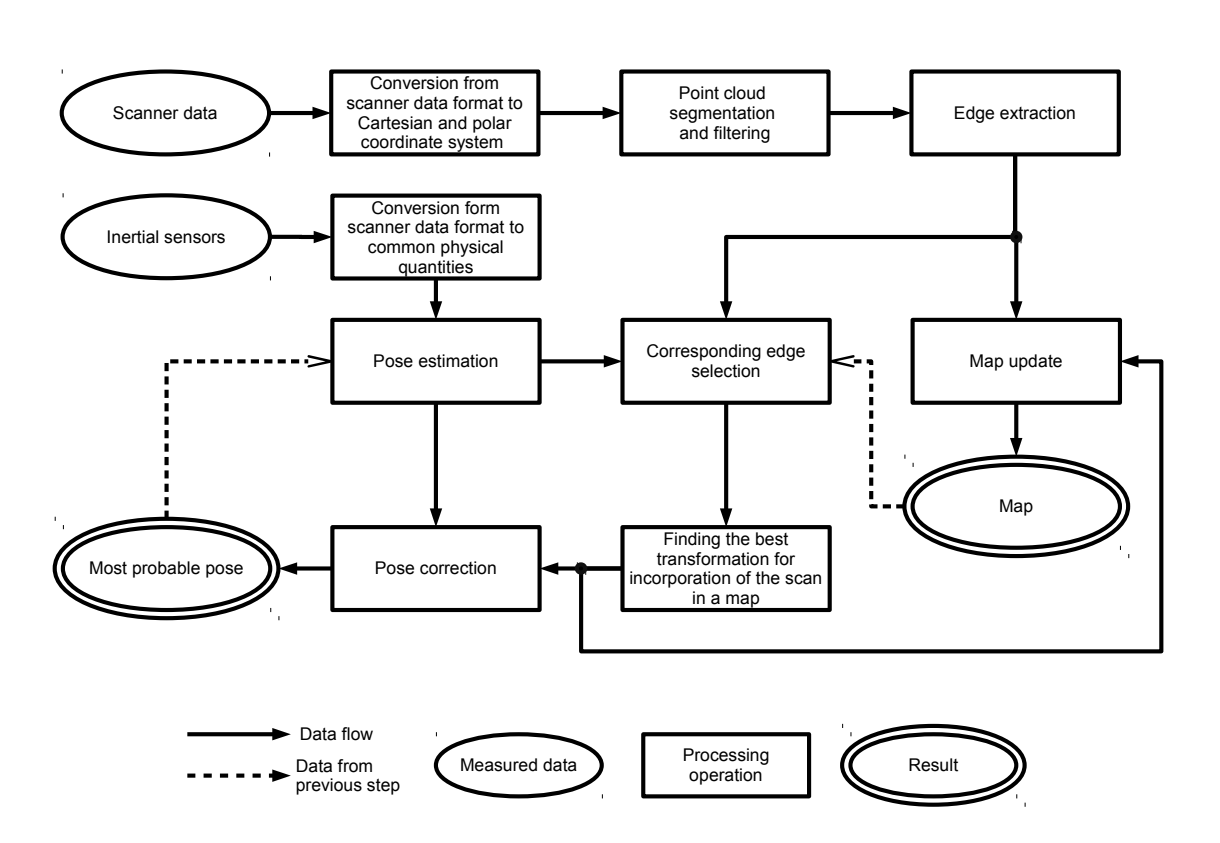
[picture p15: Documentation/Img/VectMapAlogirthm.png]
                
                \caption{Ogólny schemat przetwarzania punktów w mapę wektorową}
                Źródło: \citetitle{vector_map}\cite{vector_map}
                \label{fig:buildVectMap}
            \end{figure}

            Na ilustracji (rys. \ref{fig:buildVectMap}) zaprezentowano schemat algorytmu budowy takiej mapy, który jak można zauważyć, nie należy do najprostszych.
            Wymaga bardzo precyzyjnego próbkowania, nie ograniczającego się do minimalnej liczby punktów pomiarowych, a najlepsze rezultaty osiąga przy pełnym skanowaniu otoczenia.
            Co więcej, metoda ta wymusza nadmiarowość — każdy nowy obszar musi częściowo pokrywać się z wcześniej zmapowanym terenem.
            Obliczenie zmiany położenia oraz łączenie punktów w wektory jest czasochłonne, a wyznaczanie trasy na skomplikowanym planie trwa długo.
            Na schemacie \ref{schematic:vectorMapPathfinding} przedstawiono algorytm sprawdzania kolizji na ścieżce dla przestrzeni wektorowej.

            \input{Schematic/vectMapPathfinding.tex}

            Olbrzymią zaletą takich map jest możliwość nielimitowanego skalowania — w przeciwieństwie do obrazów rastrowych nie występuje w nich efekt "pikselizacji".
            Dodatkowo charakteryzują się one niewielkim rozmiarem przy zachowaniu dużej szczegółowości.

\newpage
        \subsubsection{Mapa rastrowa}
            Ostatnią zaproponowaną koncepcją jest mapa rastrowa.
            W tym przypadku dzielimy całą przestrzeń na równe kwadraty, a każdy z nich opisuje jeden z kilku możliwych stanów,
            na przykład:
            \begin{enumerate}
                \item pole nieznane,
                \item pole wolne,
                \item pole zajęte.
            \end{enumerate}

            Z drugiej strony wadą tej metody jest dyskretyzacja obszaru, która w zależności od stopnia zaawansowania może znacznie przekłamywać rzeczywistość.
            Przykładowo, dla jednego segmentu o wymiarach $100mm \times 100mm$ mniejsze obiekty mogą być albo całkowicie niewidoczne, albo przeszacowane.
            Dlatego niezwykle ważne jest, aby dostosować rozmiar pojedynczej kratki, zarówno do wielkości pojazdu, jak i całej przestrzeni.

            Następnym problemem jest pokaźna ilość pamięci potrzebna do przechowywania takiej powierzchni.
            Dla mapy o wymiarach $10m \times 10m$ i komórkach $100mm \times 100mm$ otrzymujemy:
            \begin{gather}
                V_{\text{size}} = \frac{10m}{100mm} \cdot \frac{10m}{100mm} \cdot 2bit = 20kbit
            \end{gather}

            Taką strukturę należało również optymalnie rozłożyć w pamięci, tak aby możliwy był szybki dostęp do grupy segmentów.
            Dla programu odnajdowania ścieżek nie jest istotne, czy pole jest nieznane, czy wolne, w obu przypadkach algorytm zachowa się tak samo.
            Z tego powodu można ograniczyć ilość bitów na kratkę do jednego.
            Dodatkowo możemy ułożyć poszczególne komórki w zbiory odpowiadające większym kwadratom.
            I tak:
            \begin{itemize}[label = -]
                \item osiem komórek w rzędzie to jeden bajt,
                \item osiem rzędów to jeden wiersz, a więc osiem bajtów,
            \end{itemize}
            dzięki czemu odczyt całego wiersza jest błyskawiczny.
            Jednocześnie procesor nie musi za każdym razem zwracać się do pamięci, jeśli chce odczytać informacje o następnej komórce.

            Ze względu na swoją prostotę i łatwość implementacji to właśnie ten sposób przechowywania mapy został zastosowany w projekcie.
            Dla tej metody policzono średni czas potrzebny na wyznaczenie ścieżki na drodze testowej przedstawionej na rysunku \ref{fig:pathFindingTime}, który wyniósł $t=100ms$.
%
            \begin{figure}
                \centering
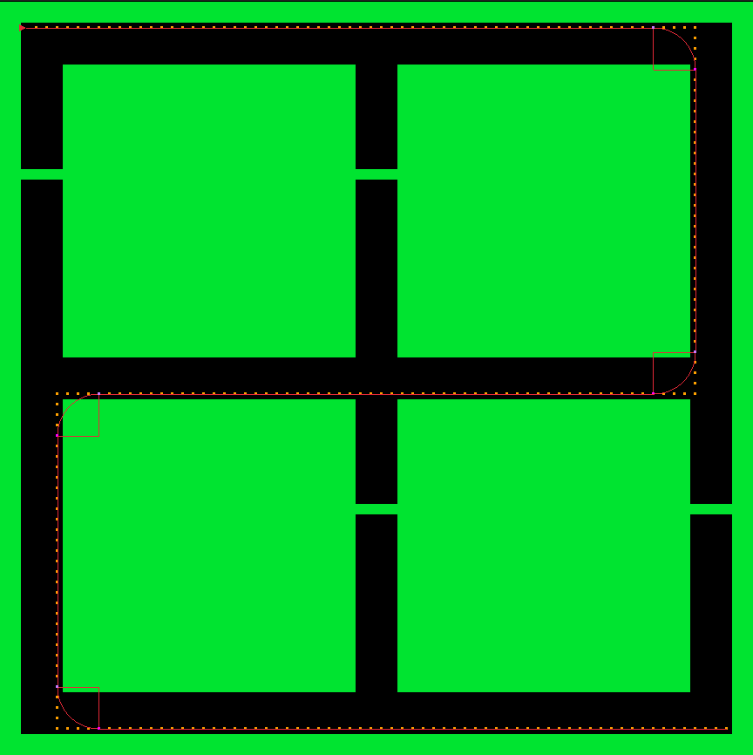
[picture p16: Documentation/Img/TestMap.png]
                
                \caption{Pomiar czasu wyznaczania ścieżki}
                Wymiary mapy: 72 komórki na 72 komórki
                \label{fig:pathFindingTime}
            \end{figure}
%
            Złożoność mapy ma niewielki wpływ na czas wyznaczenia trasy.
            Dla pustej mapy wartość ta oscylowała wokół $95ms$.
            Pozycja pojazdu oraz odległość od celu, niczego nie zmieniają.

    \subsection{Nanoszenie punktów pomiarowych}
        Jednym z podstawowych założeń była możliwość budowania mapy przez robota.
        W tym celu samochód musi mierzyć odległość w trakcie ruchu.
        Czujniki ToF zamontowane na przedzie pojazdu zostały ustawione w tryb ciągłej pracy z okresem $T ms$.
        Takie ustawienie pozwala na regularne odczytywanie dystansu, bez konieczności zajmowania procesora procedurą pomiarową.

        \subsubsection{Okres wykonywania pomiarów}
            Czas odebrania danych od pojedynczego modułu wynosi około $3ms$.
            Okres pomiarowy powinien być na tyle długi, aby pozwolić na odczytanie wszystkich czujników.
            Wartość $T$ musi być większa od $9ms$.
            Okres ten został ustawiony na $T = 100ms$.
            Dzięki temu pojazd jest w stanie w miarę na bieżąco reagować na zdarzenia, a jednocześnie mikrokontroler nie zajmuje się wyłącznie pomiarami.

        \subsection{Przykładowa mapa}
            Regularne próbkowanie oraz znajomość przebytej drogi między każdym z odcinków pozwala na dokładne określenie, w którym miejscu zostały wykonane poszczególne pomiary.
            Poniżej przedstawiono zrzut ekranu (rys. \ref{fig:buildMap}) z aplikacji z początkiem budowanej mapy o wymiarach $ 2.4m \times 2.4m$ i wielkości pojedynczej kratki $100mm \times 100mm$.

            \begin{figure}[!ht]
                \centering
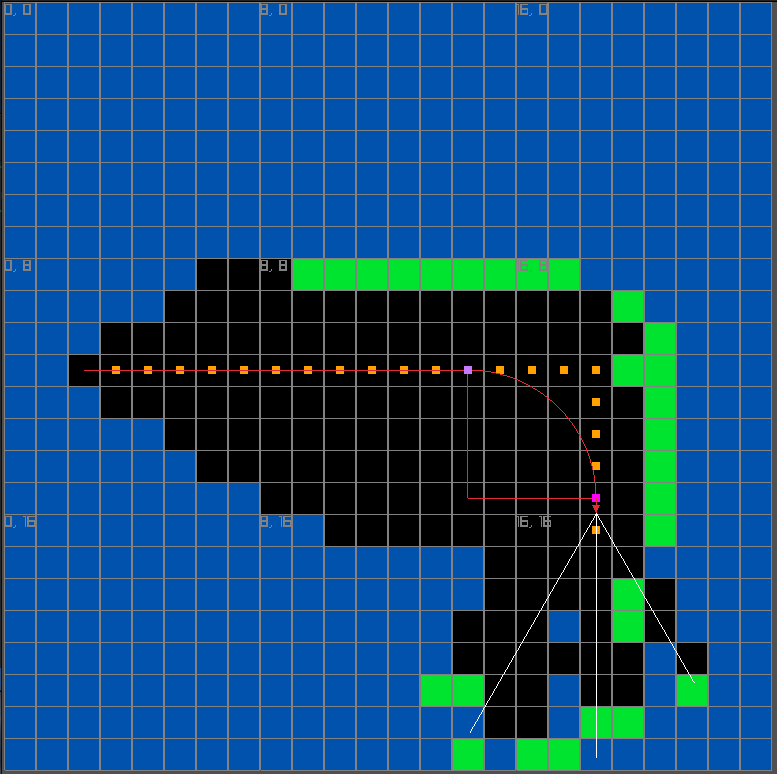
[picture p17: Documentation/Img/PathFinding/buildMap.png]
                
                \caption{Zbudowana mapa}
                \label{fig:buildMap}
            \end{figure}

            \input{Schematic/room.tex}

            Na schematycznym rysunku \ref{schematic:room} zaprezentowano rzut powierzchni, po której pojazd przemieszczał się.
            Czerwonymi kropkami oznaczono przybliżone miejsca zatrzymania się, a linia przerywana pokazuje pokonaną trasę.
            Jak widać, odzwierciedlenie mapy stworzonej przez robota jest dość dokładne względem rzeczywistego terenu.

            Zauważalne są pewne zniekształcenia, wynikające prawdopodobnie z niskiej rodzielczości mapy oraz nieidealność algorytmu rysującego.
            Pomimo tego wykonaną próbę można uznać za udaną.

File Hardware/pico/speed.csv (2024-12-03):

Continue
Speed: 13107
12630436 | 0.00 | 0.00
12732391 | 0.00 | 0.00
12834222 | 0.00 | 0.00
12936036 | 0.00 | 0.00
13037845 | 0.00 | 0.00
13139654 | 0.00 | 0.00
13241464 | 0.00 | 0.00
13343272 | 0.00 | 0.00
13445083 | 0.00 | 0.00
13546895 | 0.00 | 0.00
13648704 | 0.00 | 0.00
13750514 | 0.00 | 0.00
13852322 | 0.00 | 0.00
13954131 | 0.00 | 0.00
14055939 | 0.00 | 0.00
14157749 | 0.00 | 0.00
14259557 | 0.00 | 0.00
14361366 | 0.00 | 0.00
14463178 | 0.00 | 0.00
14564987 | 0.00 | 0.00
14666796 | 0.00 | 0.00
14768606 | 0.00 | 0.00
14870419 | 0.00 | 0.00
14972225 | 0.00 | 0.00
15074031 | 0.00 | 0.00
15175837 | 0.00 | 0.00
15277647 | 0.00 | 0.00
15379457 | 0.00 | 0.00
15481267 | 0.00 | 0.00
15583075 | 1.64 | 1.47
15684898 | 17.02 | 16.03
15786889 | 42.38 | 39.27
15888881 | 73.30 | 67.25
15990881 | 106.84 | 96.04
16092959 | 142.19 | 118.79
16195126 | 178.67 | 135.80
16297291 | 215.81 | 148.40
16399457 | 253.28 | 156.58
16501623 | 290.92 | 162.31
16603788 | 328.55 | 166.40
16705954 | 366.34 | 169.35
16808123 | 404.14 | 172.29
16910288 | 442.10 | 176.71
17012458 | 479.57 | 191.76
17114624 | 517.04 | 215.65
17216786 | 553.36 | 244.61
17318955 | 584.61 | 276.19
17421119 | 610.79 | 308.91
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

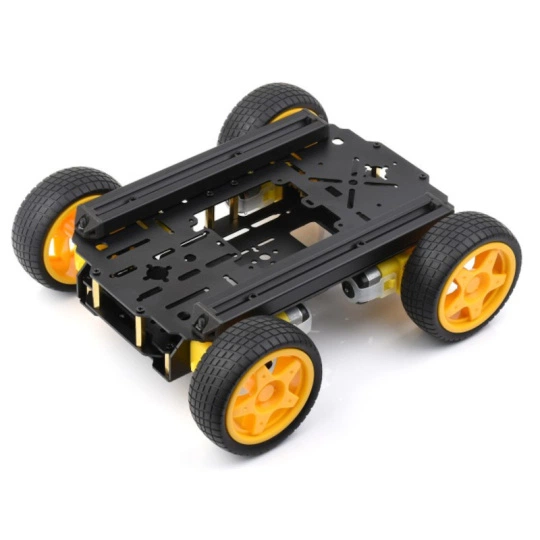
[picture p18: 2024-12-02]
Documentation/Img/chassis-waveshare-24419.webp

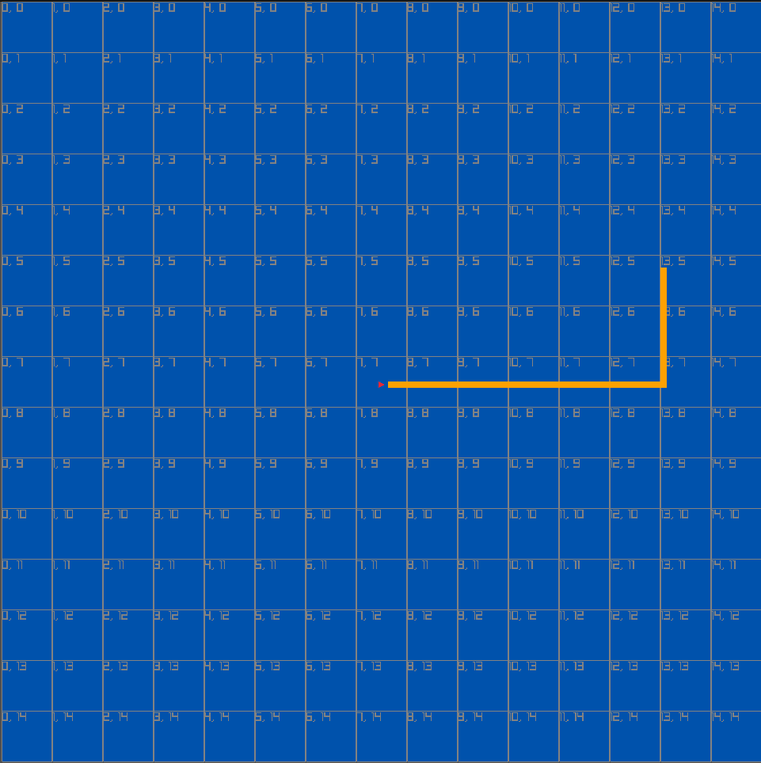
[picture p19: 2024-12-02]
Documentation/Img/PathFinding/Dikstra_pathFinding_rightTurn.png

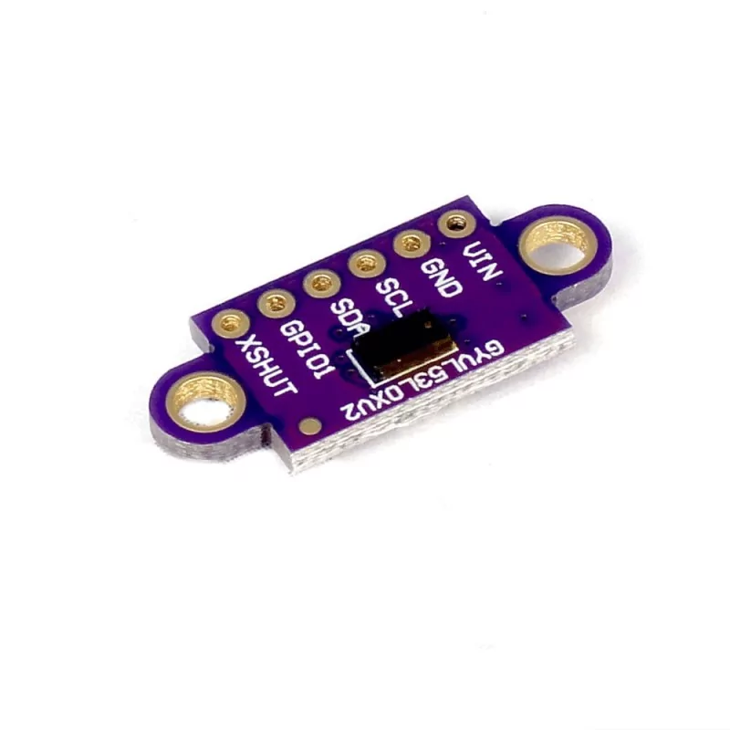
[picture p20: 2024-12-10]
Documentation/Img/tof.png

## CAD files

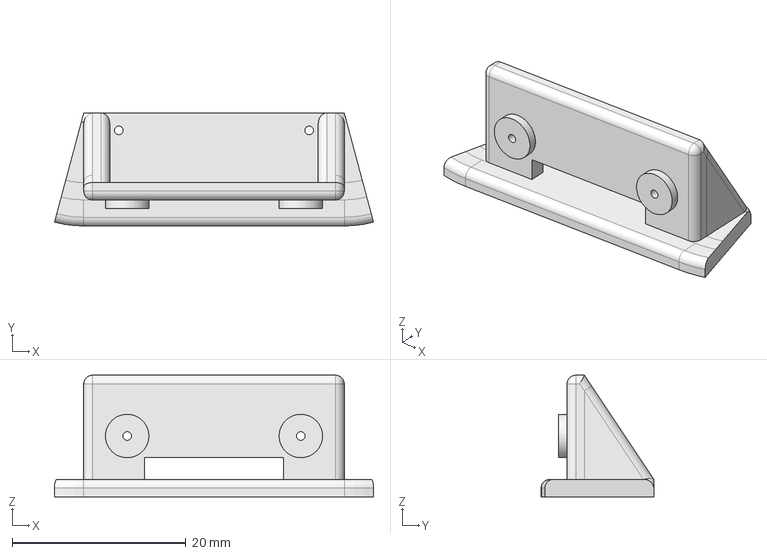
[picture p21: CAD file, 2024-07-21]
Modele/ToF_holder.FCStd
36.7 x 13.0 x 14.0 mm

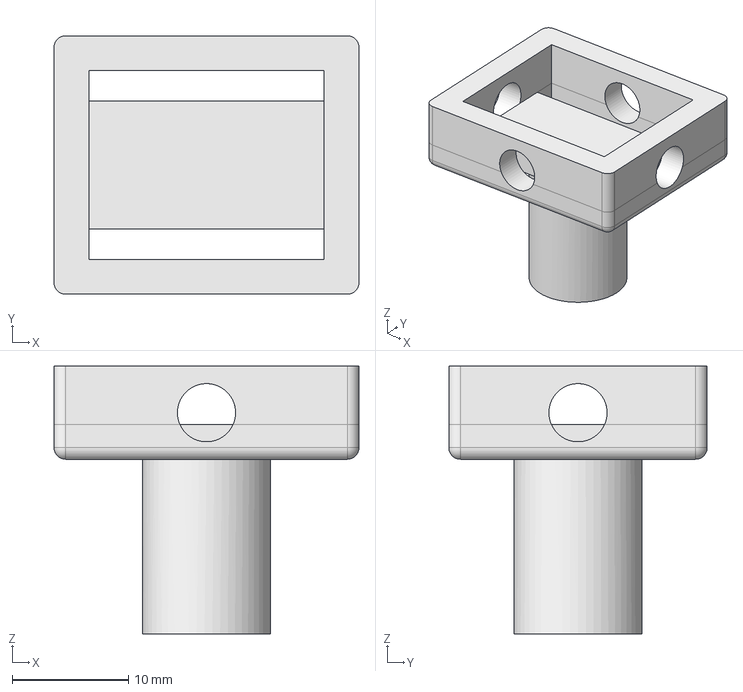
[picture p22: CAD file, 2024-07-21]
Modele/CalibrationHolder_MPU6050_longLeg.FCStd
26.2 x 22.2 x 23.0 mm

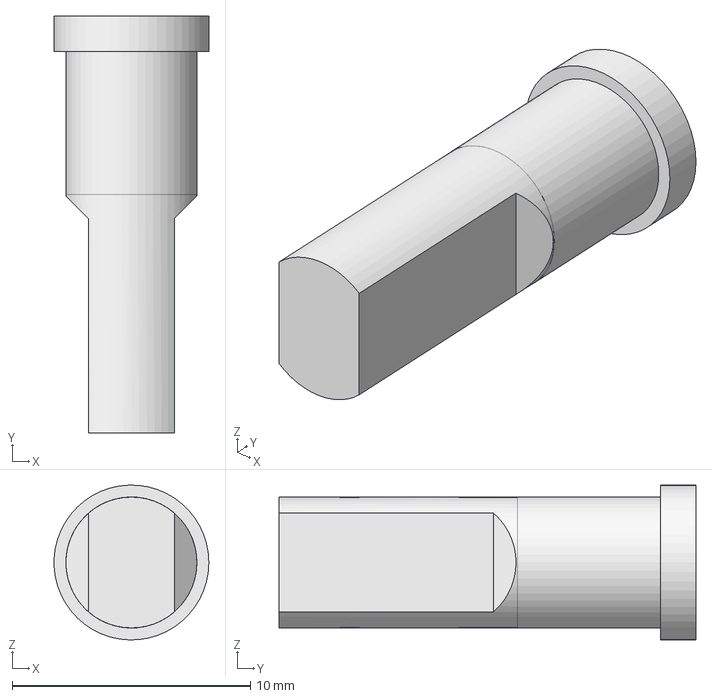
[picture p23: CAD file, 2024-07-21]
Modele/FrontWheelHolder.FCStd
6.49 x 17.5 x 6.50 mm

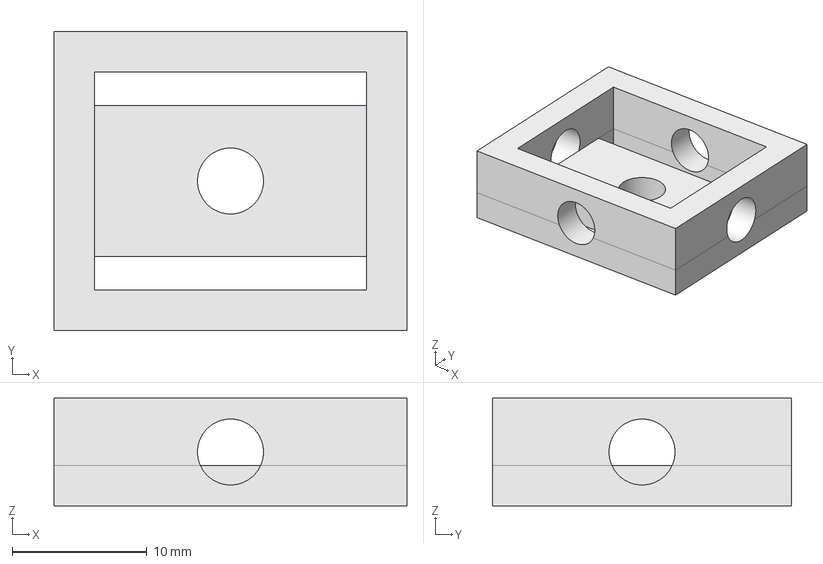
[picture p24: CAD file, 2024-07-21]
Modele/CalibrationHolder_MPU6050.FCStd
26.2 x 22.2 x 8.00 mm

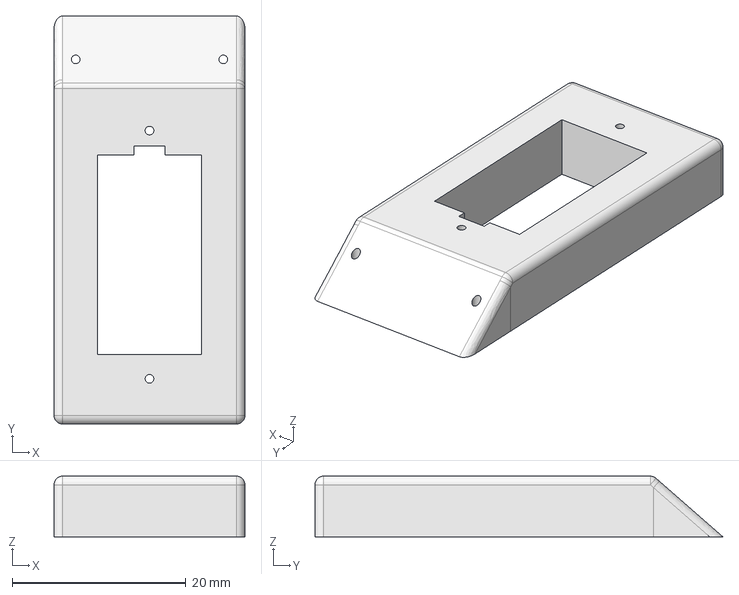
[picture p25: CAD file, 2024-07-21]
Modele/ServoHolder.FCStd
22.0 x 47.0 x 7.00 mm

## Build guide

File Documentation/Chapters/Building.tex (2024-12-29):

\section{Budowa pojazdu}
\label{sec:building}
    Inspiracją do stworzenia poniższego projektu były samochody autonomiczne, które najczęściej są pojazdami dwuosiowymi, z jedną osią skrętną i jedną napędową.
    Żadna z nich nie jest ze sobą połączona, co pozwoliło na niezależne sterowanie.
    W konstrukcji zostały użyte dwa silniki prądu stałego, wybrane w rozdziale \ref{sec:engines}, połączone bezpośrednio do tylnych kół.
    \subsection{Przednia oś}
    \label{subsec:drive_axis}
        Układ kierowniczy oparto na serwomechanizmie.
        Na rysunku \ref{fig:frontAxis_model} przedstawiono model tego elementu, zaprojektowanego przez autora.

        \begin{figure}[!ht]
            \centering
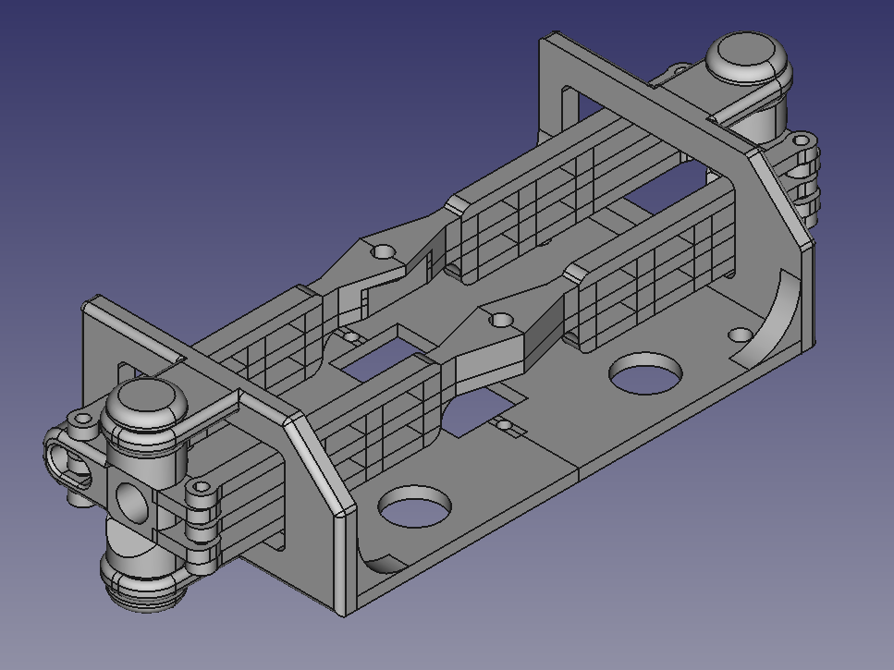
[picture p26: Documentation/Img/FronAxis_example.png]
            
            \caption{Przykładowy układ kierowniczy zaprojektowany w narzędziu FreeCAD}
            \label{fig:frontAxis_model}
        \end{figure}
        Mechanizm ten został rozplanowany w taki sposób, aby środek osi znajdował się w linii ze środkiem serwomechanizmu.
        Dzięki temu ustawiony kąt serwa, odpowiada kątowi skrętu kół.
        Natomiast dużą wadą takiego połączenia jest możliwość jego uszkodzenia, po przekroczeniu maksymalnego zakresu ruchu.

    \subsection{Rama pojazdu}
    Do budowy podwozia została wykorzystana gotowa rama, z poniższego zdjęcia (rys. \ref{fig:test_chassis}), produkowana przez firmę Waveshare.
\clearpage
    \begin{figure}[!ht]
        \centering
        
        \caption{Rama Waveshare 24419}
        Źródło: \href{https://www.waveshare.com/robot-chassis.htm?sku=24419}{waveshare.com}
        \label{fig:test_chassis}
    \end{figure}

    Aby spełnić założenia projektowe, przednia oś konstrukcji została wymieniona na wyżej opisaną (rozdział \ref{subsec:drive_axis}).
    Dodatkowo zmieniono sposób montażu silników, które zamontowano odwrotnie do zaleceń producenta (rys. \ref{fig:motors}), a także zrezygnowano z ,,gumek", odpowiadających za amortyzację.

    \input{Schematic/motors.tex}

    \subsection{Pomiar odległości}
        Współczesne pojazdy autonomiczne wykorzystują układy LIDAR, które pozwalają mierzyć w~pełnym zakresie $360^\circ$.
        Jednak w wielu sytuacjach taki pomiar mija się z celem, gdyż znaczna część próbek zostaje odrzucona.
        Same LIDARy zaś są bardzo drogimi urządzeniami, często z~niestandardowym sposobem komunikacji (np. za pomocą UART).
        Z tego względu autor zdecydował się na zastosowanie tańszych czujników ToF.
        Trzy takie moduły umieszczono z przodu samochodu, z krokiem co $30^\circ$.
        Na rysunku \ref{fig:ToF_holder} zaprezentowano model mocowania wyżej wymienionych elementów.

        \begin{figure}[!ht]
            \centering
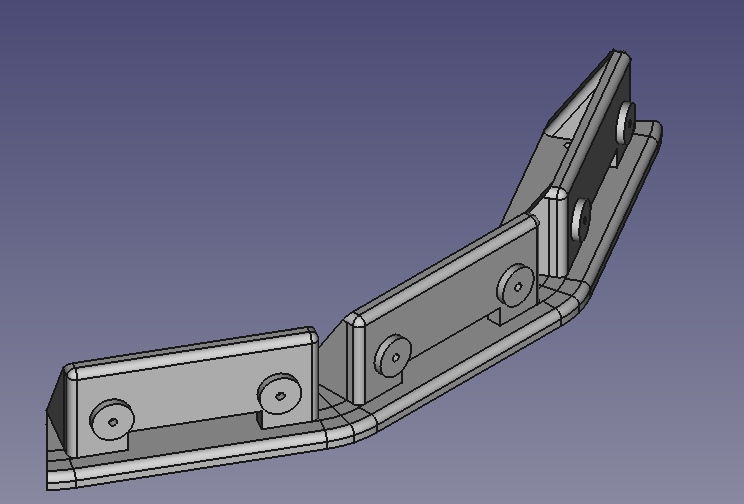
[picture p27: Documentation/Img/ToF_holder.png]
            
            \caption{Mocowanie czujników ToF}
            \label{fig:ToF_holder}
        \end{figure}

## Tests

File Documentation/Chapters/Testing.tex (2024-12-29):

\section{Środowisko testowe}
\label{sec:testing}
    Podczas budowy dowolnego systemu, niezwykle ważne jest testowanie elementów składowych.
    Połączone moduły również wymagają sprawdzenia ich współpracy.
    W informatyce kontrolę oprogramowania zapewniają testy jednostkowe, które weryfikują działanie poszczególnych algorytmów i programów.
    Natomiast w przypadku prac nad sprzętem niezbędne jest zbudowanie odpowiedniego środowiska, pozwalającego na testowanie każdego elementu osobno oraz łącznie poszczególnych podzespołów w bloki funkcjonalne.
    Dlatego wykonanie fizyczne należy podzielić na kilka etapów, opisanych poniżej:
    \begin{enumerate}
        \item Budowa prototypu na płytce stykowej.
        \item Złożenie ramy pojazdu z elektroniką umieszczoną na płytce stykowej wraz z doprowadzonym zewnętrznym zasilaniem.
        \item Sprawdzenie działania pojazdu z płytką stykową zasilaną bateryjnie.
        \item Wykonanie płytki prototypowej z połączeniami wszystkich elementów na stałe ponownie z zewnętrznym zasilaniem.
        \item Sprawdzenie działania prototypu pojazdu z zasilaniem akumulatorowym.
    \end{enumerate}
    Każdy z wymienionych kroków charakteryzował się innym rodzajem testów oraz własnymi problemami.
    Zakończenie jednej fazy i przejście do następnej było możliwe dopiero po uznaniu przez autora, że układ pracuje poprawnie.

    \subsection{Modele prototypowe}
        Pierwszym etapem było zbudowanie na podstawie schematu z rysunku \ref{schema:block} modelu elektronicznego na płytce stykowej.
        Poniżej przedstawiono zdjęcie układu złożonego w ten sposób.
        Obwód ten pozwalał na bezpieczne testowanie nowych funkcji, bez ryzyka uszkodzenia elementów.
        Dodatkowymi zaletami takiego połączenia są: możliwość bezpośredniego debugowania kodu oraz szybka wymiana modułów w przypadku konfliktów między poszczególnymi blokami.
        \begin{figure}[!ht]
            \centering
            
            \caption{Model prototypowy na płytce stykowej}
            \label{fig:breadboard}
        \end{figure}

        Tak zbudowany obwód działał bez zarzutu, dzięki czemu możliwe było przejście do następnej fazy pracy.

        W tym celu system z rysunku \ref{fig:breadboard} został skompresowany, aby zmieścił się na pojedynczej mniejszej płytce.
        Następnie układ zamocowano na samochodzie.
        Do tego celu zaprojektowano obudowę, którą przykręcono do całości, po czym umieszczono w niej zminiaturyzowany system.
        Na zdjęciu poniżej (rys. \ref{fig:breadboard_car}) przedstawiono opisaną sytuację.

        Pojazd wyposażono w dwa pojedyncze koszyki na akumulatory oraz moduł BMS (Battery Management System).
        Dzięki temu całość mogła pracować na zasilaniu bateryjnym bez obawy o uszkodzenia.

        \begin{figure}[!ht]
            \centering
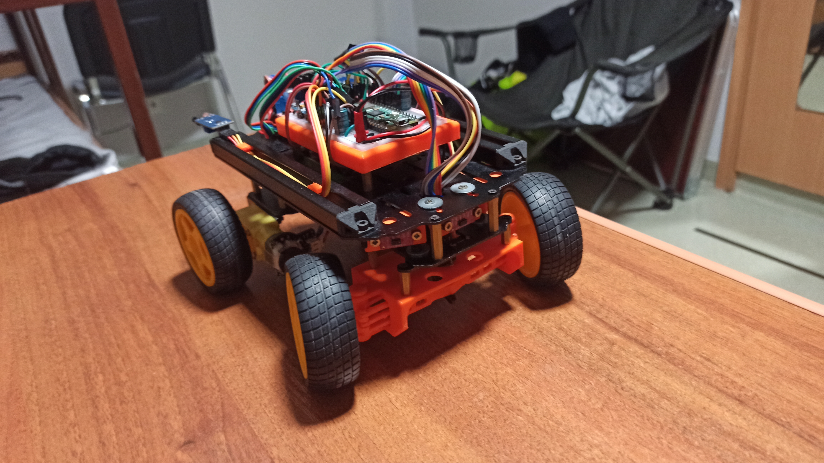
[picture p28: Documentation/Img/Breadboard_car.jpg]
            
            \caption{Pojazd z zainstalowaną płytą stykową}
            \label{fig:breadboard_car}
        \end{figure}

        Po zamocowaniu płytki do ramy samochód został poddany prostym testom, które polegały na sprawdzeniu działania wszystkich komponentów.
        Następnie zbadano podstawowe funkcje takie jak: jazda prosto czy skręcanie.

        W czasie kontroli poszczególnych elementów pojedynczo, wszystko działało poprawnie.
        Natomiast po dłuższym czasie testy wykazały, że układ akcelerometru potrafi zawiesić się w przypadkowym momencie.
        Jednocześnie zawieszając pracę mikrokontrolera.
        Problematyczna okazała się linia $SDA$ protokołu $I^2C$.
        Jeden z czujników po spadku napięcia, zwierał tę linie do masy, co uniemożliwiało dalszą pracę.

        Pierwszą próbą rozwiązania było zastosowanie się do instrukcji z noty aplikacyjnej od Analog Devices o resetowaniu linii $I^2C$ \cite{application_note_I2C_AD}.
        Podobną sugestię można znaleźć w dokumentacji do tej magistrali \cite{I2C_manual_NXP} wydanej przez NXP.
        Obaj producenci radzą, aby w takiej sytuacji spróbować ręcznie wyczyścić zablokowaną linię danych, wysyłając od 8 do 16 cykli zegara.
        % W ten sposób, zablokowane urządzenie powinno zwolnić linię $SDA$.
        W ten sposób linia $SDA$ powinna zostać zwolniona.
        Niestety przedstawiony mechanizm nie przyniósł oczekiwanych rezultatów.

        Drugim sposobem sugerowanym przez oba dokumenty,
        w sytuacji kiedy nie udało się ustawić magistrali jest zresetowanie niedziałających (w domyśle wszystkich) układów.
        To rozwiązanie mimo swojej skuteczności nie zostało wykorzystane,
        ze względu na bardzo długi czas ponownej inicializacji czujników.
        Autor skupił się na znalezieniu pierwotnej przyczyny, którą okazała się płytka stykowa.
        Podczas jazdy cały pojazd drżał, co powodowało, że niektóre piny nie kontaktowały,
        a w konsekwencji akcelerometr po spadku zasilania, blokował magistralę.
        Zlikwidowanie problemu na tym etapie, okazało się niemożliwe, z powodu działania zastosowanej metody połączeń.
        Jedynym wyjściem było zbudowanie lepszej wersji prototypu.
        % Natomiast kolejny prototyp nie posiadał tego problemu.

        Niespodziewaną zaletą powyższych zmagań było udoskonalenie funkcji odpowiedzialnych za kontrolę protokołu $I^2C$.
        Na początku proces przesyłania danych między czujnikami, blokował pracę całości.
        Czekanie na wynik, sprawdzało się tak długo jak wszystkie moduły odpowiadały poprawnie.
        Jednak luźne połączenia między płytką stykową a pinami elementów ukazały,
        że~wstrzymywanie kontrolera do momentu uzyskania odpowiedzi jest niepraktyczne ze względu na blokadę sterowania.
        W ulepszonej wersji kodu dla mikrokontrolera, podczas transmisji danych procesor uwzględnia maksymalny czas na odpowiedź.
        Po przekroczeniu tego limitu, program zgłasza błąd $ERROR\_PICO\_TIMEOUT$, sygnalizujący o niepowodzeniu wymiany informacji.

        Ostatnią testowaną wersją układu jest zlutowana na stałe płytka prototypowa.
        Taka budowa pozwoliła pozbyć się niektórych problemów, przykładowo blokowania się magistrali $I^2C$.
        Jednak i na tym etapie pojawiły się inne mankamenty, które ukrywała płytka stykowa.
        \begin{figure}[!ht]
            \centering
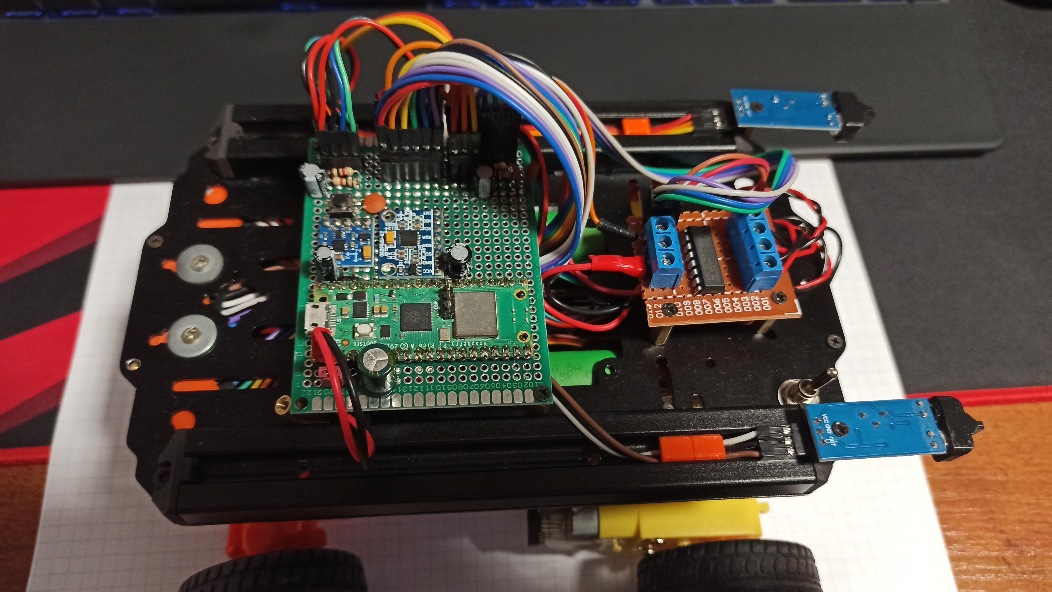
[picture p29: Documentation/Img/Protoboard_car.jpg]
            
            \caption{Model pojazdu z zainstalowaną płytą prototypową}
            \label{fig:protoboard_car}
        \end{figure}

        Największą wadą, która ukazała się podczas testowania tej fazy, było losowe resetowanie się Raspberry Pi Pico.
        Sytuacja ta występowała czasami, zarówno po podłączeniu zewnętrznego zasilacza jak i pracy na akumulatorach.
        Kłopotliwa stała się jednoczesna praca silników i~enkoderów.
        Po odłączeniu wyjść sygnałowych enkoderów, układ przestał się restartować.
        Aby upewnić się, że przyczyną są uszkodzone enkodery, w szeregu z ich wyjściami zostały podłączone rezystory o wartości $1k\Omega$, które chroniły układ przed zwarciem.
        Tak zabezpieczony system powinien pracować poprawnie, jednak restarty nadal występowały.

        Następną próbą było rozseparowanie zasilania.
        W ten sposób silniki zostały podłączone bezpośrednio do zasilacza laboratoryjnego, natomiast Raspberry Pi wraz z pozostałymi modułami do złącza USB.
        Uruchomienie całości w takiej konfiguracji, natychmiast zresetowało procesor.
        Kolejną propozycją była zmiana mostka H na inny, co również nie pomogło.
        Podczas składania prototypu, uszkodzeniu uległ jeden z czujników ToF.
        Po wymianie tego układu, problem nie zniknął.
        Ostatnim co mogło zostać uszkodzone, był sam kontroler, jednak jego wymiana również nie przyniosła oczekiwanego efektu.

        Rozwiązanie okazało się dość prozaiczne.
        Z braku lepszego pomysłu, autor dołożył dużą rozproszoną pojemność (około $500\mu F$) na całej płytce, co okazało się zbawienne dla pracy procesora.

        W tej generacji projektu, uwidoczniły się błędy, wynikające z oscylacji na liniach sygnałowych od czujników obiektów, zamontowanych na tyle pojazdu.
        Drgania te, nie pozwalały na jazdę wstecz, ponieważ układy przy ruszeniu natychmiast zgłaszały przerwanie, a w konsekwencji program zatrzymywał silniki.
        Wyjściem z sytuacji było zastosowanie dolnoprzepustowych filtrów RC, niwelujących spadki zasilania, występujące podczas startu.

    \subsection{Testy automatyczne}
    \label{sec:auto_test}
        Automatyzacja pracy jest niezwykle ważnym zadaniem.
        Istnieje wiele gotowych narzędzi, specjalnie przeznaczonych do tego procesu.
        Autor jednak zdecydował się, na napisanie własnego programu, którego podstawowymi założeniami są: dwukierunkowa komunikacja, zapisywanie odebranych danych do pliku oraz czytanie i wykonywanie podprogramów.
        Dodatkową opcją ma być możliwość wywołania każdej funkcji ręcznie,
        w taki sposób, aby całość była przejrzysta dla użytkownika - proces analizy kodu i pracy manualnej, nie powinien wymuszać każdorazowego uruchomienia aplikacji.

        Aby wykonać to zadanie, w języku Python został napisany skrypt, który pozwala na dwustronną transmisję za pomocą protokołu $UDP$.
        Dzięki temu użytkownik może wysyłać komendy do mikrokontrolera, a równocześnie program nasłuchuje odpowiedzi i wyświetla wyniki.
        Co więcej instrukcja $file\ \{path\}$ pozwala na interpretację podprogramów, napisanych wyłącznie dla tego układu.
        Przykład takiego kodu przedstawiono na listingu \ref{list:self_test.s}.
        % Poniżej w listingu \ref{list:self_test.s} przedstawiono przykład kodu do testowania pojazdu.

        \lstinputlisting[style=asm, caption={Test pojazdu}, label = list:self_test.s]{Listing/self_test.s}

        \subsubsection{Interpreter własnego języka}
            Przedstawiony kod (listing \ref{list:self_test.s}) jest interpretowany, przez wyżej wymieniony skrypt (rozdz. \ref{sec:auto_test}).
            Działanie interpretera polega na: sformatowaniu instrukcji, wyznaczaniu adresów skoków oraz stworzeniu słownika ze zmiennymi.
            Następnie program przechodzi do wykonywania poleceń, zapisanych w pliku.
            Powyższy język posiada tylko kilka słów kluczowych, przedstawionych w~tabeli~\ref{table:keywords}.

            \begin{table}[!ht]
                \centering
                \caption{Lista słów kluczowych do mini języka}
                \begin{tabularx}{0.8\textwidth}{|c|c|C|}\hline
                    Nr. & Instrukcja & Opis \\\hline
       \centerY{2}{ 1.} & \centerY{2}{$etykieta$\textbf{:}} & Etykieta funkcji, koniecznie zakończona znakiem ,,:''\\\hline
                     2. & jump $etykieta$ & Skok do $etykiety$ \\\hline
                     3. & end & Koniec programu lub funkcji \\\hline
                     4. & print $zmienna/napis$ & Wypisanie wartości zmiennej lub napisu\\\hline
       \centerY{2}{ 5.} & \centerY{2}{if $warunek$} & Instrukcja warunkowa, w przypadku niespełnienia pomija następną instrukcję\\\hline
       \centerY{3}{ 9.} & \centerY{3}{$\$zmienna$} & Odwołanie do zmiennej. Podczas formatowania polecenia, $\$zmienna$ zostaje podmieniona na wartość\\\hline
       \centerY{3}{10.} & \centerY{3}{$zmienna$ = \textit{wartość}} & Przypisanie wartości do zmiennej. Pozwala na wykonywanie operacji matematycznych\\\hline
       \centerY{1}{11.} & \centerY{1}{$zmienna$ == $zmienna$} & Porównanie dwóch wartości\\\hline
       \centerY{2}{12.} & \centerY{2}{sleep $zmienna$} & Zatrzymaj wykonywanie kodu na czas ze~$zmiennej$\\\hline
                \end{tabularx}
                \label{table:keywords}
            \end{table}

            Wszystkie pozostałe instrukcje, które nie są zdefiniowane w tabeli \ref{table:keywords}, ulegają formatowaniu i wysłaniu do mikrokontrolera.
            W celu ich wyróżnienia, w konsoli bezpośrednio przed nimi zostaje wyświetlony łańcuch ,,$>>>$''.
            % W celu rozróżnienia komend wysyłanych do pojazdu a tych odebranych w trakcie interpretacji kodu, polecenia  poprzedzone są łańcuchem znaków ,,$>>>$''.
            Natomiast odebrane dane i wyniki polecenia $print$ są identyczne i niepoprzedzone żadnym znacznikiem.
            % Natomiast wynik polecenia $print$ jest identyczny z tym, co zwraca Raspberry Pi Pico.

            W przypadku kiedy dyrektywa zostaje odnaleziona, ale zawiera błąd składniowy, program wypisuje informacje o napotkanym problemie i przerywa działanie.
            Przykład takiej sytuacji przedstawiono na zdjęciu poniżej (rys. \ref{fig:interpreter}).

            \begin{figure}[!ht]
                \centering
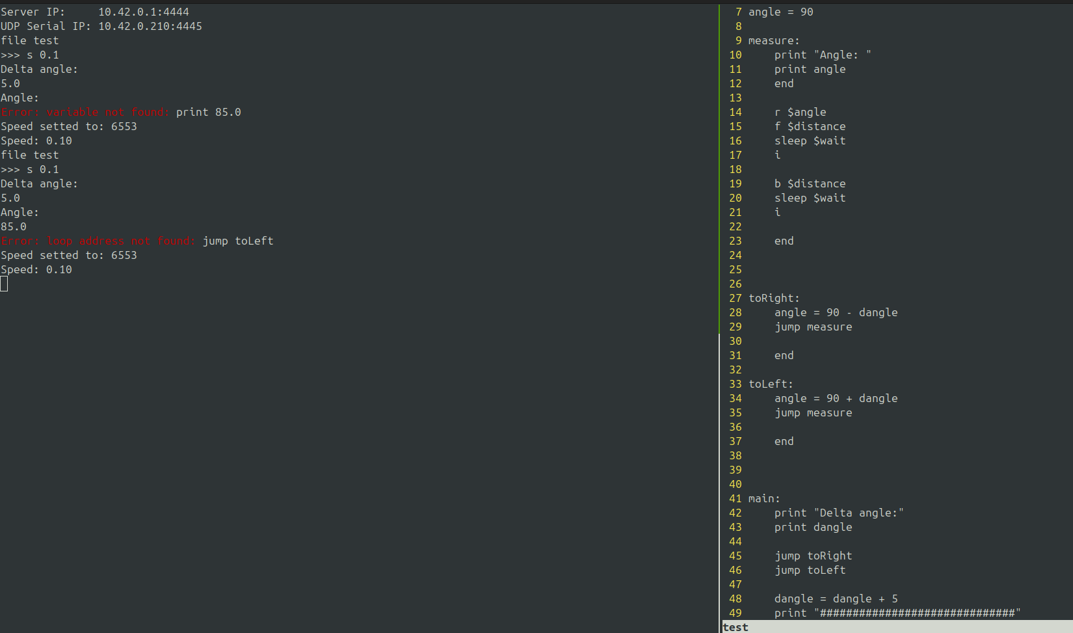
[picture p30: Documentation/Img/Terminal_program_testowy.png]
                
                \caption{Program zawierający celowe błędy}
                \label{fig:interpreter}
            \end{figure}

            Praca interpretera jest równoległa z odczytywaniem danych, dlatego zdarza się, że pomimo niepowodzenia program wyświetla wynik ostatniej poprawnej operacji.
            Taka sytuacja wystąpiła na rysunku \ref{fig:interpreter}. Skrypt zdążył wysłać kilka poleceń do Raspberry, następnie natrafił na błąd składniowy, co zatrzymało proces.
            W tym czasie ostatnia wykonana instrukcja zwróciła wartość, a program wyświetlił jej wynik.

\newpage
\

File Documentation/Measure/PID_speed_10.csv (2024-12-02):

Time | PID_ans | Distance_err
0.0 | 0 | 0.0
0.02 | 151 | 1.087
0.04 | 1 | 1.087
0.06 | 153 | 2.175
0.08 | 3 | 2.175
0.1 | 3 | 2.175
0.12 | 307 | 4.349
0.14 | 158 | 5.436
0.16 | 312 | 7.611
0.18 | 164 | 8.698
0.2 | 317 | 10.873
0.22 | 169 | 11.96
0.24 | 171 | 13.047
0.26 | 173 | 14.134
0.28 | 175 | 15.222
0.3 | 176 | 16.309
0.32 | 178 | 17.396
0.34 | 28 | 17.396
0.36 | 180 | 18.483
0.38 | -120 | 17.396
0.4 | 181 | 18.483
0.42 | -272 | 16.309
0.44 | 27 | 16.309
0.46 | -123 | 15.222
0.48 | 26 | 15.222
0.5 | -125 | 14.134
0.52 | -127 | 13.047
0.54 | -128 | 11.96
0.56 | -130 | 10.873
0.58 | -132 | 9.785
0.6 | -133 | 8.698
0.62 | -135 | 7.611
0.64 | -440 | 4.349
0.66 | -294 | 2.175
0.68 | -145 | 1.087
0.7 | -147 | 0.0
0.72 | 2 | 0.0
0.74 | -301 | -2.175
0.76 | -1 | -2.175
0.78 | -1 | -2.175
0.8 | -1 | -2.175
0.82 | -1 | -2.175
0.84 | 150 | -1.087
0.86 | 0 | -1.087
0.88 | 303 | 1.087
0.9 | 155 | 2.175
0.92 | 5 | 2.175
0.94 | 157 | 3.262
0.96 | 159 | 4.349
0.98 | 161 | 5.436
1.0 | 162 | 6.524
1.02 | 164 | 7.611
1.04 | 14 | 7.611
1.06 | 166 | 8.698
1.08 | 16 | 8.698
1.1 | 16 | 8.698
1.12 | 168 | 9.785
1.14 | -133 | 8.698
1.16 | 16 | 8.698
1.18 | -134 | 7.611
1.2 | 166 | 8.698
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

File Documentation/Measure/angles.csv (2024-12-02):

Time | Compass_azimuth_raw | Compass_azimuth | Gyro_z_raw | Gyro_z | Delta_angle
0.004 | 151.902 | 176.645 | 0.145 | 0.01 | -0.005
0.014 | 152.058 | 176.67 | 0.206 | 0.02 | -0.003
0.024 | 151.902 | 176.702 | 0.038 | -0.016 | -0.004
0.034 | 151.912 | 176.781 | 0.015 | -0.048 | -0.009
0.044 | 151.788 | 176.745 | 0.046 | -0.064 | -0.015
0.054 | 151.917 | 176.787 | 0.008 | -0.086 | -0.024
0.064 | 151.923 | 176.774 | 0.122 | -0.074 | -0.031
0.074 | 151.855 | 176.759 | 0.267 | -0.029 | -0.034
0.084 | 152.162 | 176.914 | 0.13 | -0.029 | -0.037
0.094 | 151.657 | 176.807 | 0.137 | -0.027 | -0.04
0.104 | 151.989 | 176.812 | 0.137 | -0.026 | -0.042
0.114 | 152.265 | 176.95 | 0.259 | 0.006 | -0.042
0.124 | 152.033 | 177.012 | 0.175 | 0.008 | -0.041
0.134 | 152.201 | 177.092 | 0.229 | 0.024 | -0.039
0.144 | 152.037 | 177.105 | 0.206 | 0.029 | -0.036
0.154 | 152.329 | 177.25 | 0.168 | 0.024 | -0.033
0.164 | 152.263 | 177.36 | 0.229 | 0.035 | -0.03
0.174 | 152.354 | 177.583 | 0.107 | 0.013 | -0.029
0.184 | 152.301 | 177.801 | 0.252 | 0.033 | -0.025
0.194 | 152.055 | 177.883 | 0.122 | 0.016 | -0.024
0.204 | 152.434 | 178.112 | 0.206 | 0.023 | -0.021
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

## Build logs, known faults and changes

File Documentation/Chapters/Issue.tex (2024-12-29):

\section{Problemy konstrukcyjne}
\label{sec:problemy_konstrukcyjne}
    W poniższym rozdziale zostaną przedstawione problemy konstrukcyjne,
    które pojawiły się podczas realizacji projektu.

    \subsection{Jazda prosto}
    \label{section:jazda_prosto}
        Do jednej z najprostszych czynności pojazdów należy jazda prosto.
        Operacja ta może wydawać się łatwa, jednak wcale taka nie jest.
        Przykładowo, kiedy usiądziemy za kierownicą prawdziwego samochodu, kontrolujemy podświadomie wiele parametrów, takich jak:
        \begin{itemize}
            \item nachylenie terenu,
            \item aktualną pozycję kół,
            \item linie poziome na drodze czy pobocze drogi.
        \end{itemize}
        W przeciwieństwie do ludzi, którzy często oceniają większość parametrów ,,na wyczucie'', pojazdy autonomiczne,
        będące de facto robotami, nie mogą opierać się na odczuciu prawidłowości toru jazdy.
        Z tego względu niezbędne jest zastosowanie odpowiednich czujników, umożliwiających precyzyjną kontrolę ruchu.
        Poniżej pokrótce zostaną opisane rozwiązania, dzięki którym samochód jest w stanie jechać w linii prostej.

        \subsubsection{Różnica prędkości silników}
            Zastosowanie dwóch silników ma swoje wady i zalety.
            Olbrzymim atutem jest podwojenie mocy pojazdu.
            Jednak wielkim minusem okazało się sterowanie i nierównomierność pracy.
            Na wykresie \ref{plot:distance_err_in_time_const_speed} zaprezentowano różnicę drogi pokonanej przez każdy z nich dla jednakowego sygnału sterującego.

            \begin{figure}[!ht]
                \centering
                \begin{tikzpicture}
                    \begin{axis}[
                        width = 0.7\textwidth,
                        grid = both,
                        grid style = dashed,
                        % axis lines = middle,
                        xlabel = czas ${[s]}$,
                        ylabel = różnica odległości ${[mm]}$,
                        xmin = 0,
                        xmax = 20,
                    ]
                        \addplot[blue] table[x = Time, y = Diff, col sep = comma]{Measure/distance_no_PID_speed_50.csv};
                        \legend{Błąd odległości}
                    \end{axis}
                \end{tikzpicture}
                \caption{Wykres różnicy przebytej drogi między prawym a lewym silnikiem bez regulacji}
                \label{plot:distance_err_in_time_const_speed}
            \end{figure}

            Aby rozwiązać powyższy problem, wykorzystano regulator PID, pozwalający w trakcie pracy dostosowywać szybkość silników.
            W celu zminimalizowania początkowego błędu, podczas startu została zastosowana sztywna korekta prędkości.
            % Natomiast podczas startu została zastosowana sztywna korekta prędkości, w celu zminimalizowania początkowego błędu.
            \begin{figure}[!ht]
                \centering
                \begin{tikzpicture}
                    \begin{axis}[
                        width = 0.7\textwidth,
                        grid = both,
                        grid style = dashed,
                        xlabel = czas ${[s]}$,
                        ylabel = różnica odległości ${[mm]}$,
                        xmin = 0,
                        xmax = 60,
                    ]
                        \addplot[blue] table[x = Time, y = Distance_err, col sep = comma]{Measure/PID_speed_10.csv};
                        \legend{Błąd odległości}
                    \end{axis}
                \end{tikzpicture}
                \caption{Wykres różnicy przebytej drogi między prawym a lewym silnikiem z włączonym regulatorem PID. Prędkość pojazdu: $(35.10 \pm 0.10)\frac{mm}{s}$.}
                \label{plot:PID_distance_err_in_time}
            \end{figure}

            Jak widać na wykresie (rys. \ref{plot:PID_distance_err_in_time}), we wstępnej fazie silniki nadal nie pracują równomiernie, jednak w dłuższej perspektywie różnica odległości oscyluje wokół  $ 0\pm 3mm$.

    \subsubsection{Nieidealność podwozia}
        Kolejnym napotkanym problemem, okazała się nieidealność podwozia,
        szczególnie elementu przedstawionego na rysunku \ref{fig:frontAxis_model} oraz nierównomierne rozłożenie masy względem środka.
        Wszystkie wyżej wymienione niedokładności powodowały, że pojazd cały czas skręcał w~jedną stronę.
        Rozwiązaniem było zastosowanie pętli sprzężenia zwrotnego, opartej na czujniku $MPU6050$, który został użyty jako żyroskop, pozwalający na pomiar zmiany kąta.
        Dzięki niemu można korygować obrót samochodu.

        % Jednak jego wykorzystanie nie było bezproblemowe i wymagało dodatkowych poprawek.
        Układ akcelerometru i żyroskopu ($MPU6050$) wymagał wstępnej kalibracji.
        Na wykresie (rys. \ref{plot:gyro_magneto_measure}) zaprezentowano pomiar kąta dla obrotu pojazdu ze stałą prędkością w jednym kierunku, po wprowadzeniu poprawki do odczytanych danych.
        Poniższe zestawienie zostało wykonane w celu ustalenia liniowości pracy tego modułu.
        Źródło referencyjne stanowił uprzednio skalibrowany magnetometr ($QMC5883L$).
        Na oba czujniki został nałożony filtr dolnoprzepustowy, eliminujący szumy.

        \begin{figure}[!ht]
            \centering
                \begin{tikzpicture}
                    \begin{axis}[
                        width = 0.65\textwidth,
                        grid = both,
                        grid style = dashed,
                        xlabel = czas ${[s]}$,
                        ylabel = kąt zmierzony podczas obrotu ${[^\circ]}$,
                        ymin = -5,
                        ymax = 365,
                        xmin = 0,
                        xmax = 2.9,
                        ytick = {0, 30, ..., 360},
                        legend style={at={(0.2, 0.92)}, anchor=north},
                    ]
                        \addplot[orange] table[x = Time, y = Compass_azimuth, col sep = comma]{Measure/angles.csv};
                        \addplot[blue] table[x = Time, y = Gyro_z, col sep = comma]{Measure/angles.csv};
                        \legend{magnetometr,żyroskop}
                    \end{axis}
                \end{tikzpicture}
                \caption{Wykres pomiaru azymutu za pomocą magnetometru oraz zmiany kąta wykazanego przez żyroskop}
                \label{plot:gyro_magneto_measure}
        \end{figure}

        Wykres \ref{plot:delta_angle_with_gyro} przedstawia narastanie kąta w funkcji czasu.
        Widać liniowość pracy żyroskopu, dzięki czemu, z dużą pewnością można określić, że pojazd porusza się w linii prostej.
        %  co pozwala zaufać temu czujnikowi na tyle, aby na jego podstawie określać czy pojazd porusza się w prostej linii.

        % \begin{wrapfig}[!ht]
        \begin{figure}[!ht]
            \centering
                \begin{tikzpicture}
                    \begin{axis}[
                        width = 0.7\textwidth,
                        grid = both,
                        grid style = dashed,
                        xlabel = czas ${[s]}$,
                        ylabel = kąt zmierzony podczas obrotu ${[^\circ]}$,
                        xmin = 0,
                        xmax = 2.9,
                    ]
                        \addplot[blue] table[x = Time, y = Delta_angle, col sep = comma]{Measure/angles.csv};
                    \end{axis}
                \end{tikzpicture}
                \caption{Wykres narastania kąta, zmierzonego przez żyroskop}
                \label{plot:delta_angle_with_gyro}
        \end{figure}
        % \end{wrapfig}

\newpage
    Oba opisane rozwiązania pozwalają na równą jazdę z niewielkim odchyleniem ($\pm 2^\circ$).
    W~sytuacjach kiedy samochód zaczyna znacząco skręcać, na przykład po zderzeniu, sprzężenie zwrotne z żyroskopu wykrywa zmianę kierunku.
    Kolejny regulator PID odczytuje jej wartość i koryguje kąt serwomechanizmu, tak aby pojazd wrócił na poprzednią trasę.

    \subsection{Skręcanie}
        Naprawienie problemów z przemieszczaniem się po prostej to tylko połowa sukcesu.
        Następne mankamenty zauważono podczas próby skręcania.
        W pierwotnej wersji ustawienie stałego kąta kół oraz przejechanie tej samej drogi nie zawsze dawało ten sam rezultat.
        Dodatkowo pojazd cały czas miał tendencję do preferowania jednego kierunku.

        \subsubsection{Dyferencjał}
            \label{subsubsec:dyferencjal}
            Najprostszy do zauważenia był brak dyferencjału.
            Tylna oś samochodu posiada dwa silniki. W poprzednich testach zostały one ,,software'owo połączone sztywną belką", co powodowało poślizg w trakcie skręcania, a w konsekwencji uniemożliwiało powtarzalność manewru.

            Wyjściem z tej sytuacji jest zmiana prędkości pracy silników w zależności od promienia skrętu.
            Poniżej przedstawiono schemat algorytmu, na którego podstawie wyznaczono procentową wartość dyferencjału.
            Rysunek \ref{draw:turning_car} ilustruje zachowanie kół podczas tego ruchu.
            \input{Schematic/turning.tex}

\newpage
            Jak widać skręt pojazdu można opisać jako ruch dwóch kół po okręgach o wspólnym środku, których poszczególne prędkości liniowe nie są sobie równe.
            Jednak występuje zależność:
            \begin{gather}
                \omega_{\text{wewnęrznego koła}} = \omega_{\text{zewnętrznego koła}}\\
                \frac{v_{\text{wewnęrznego koła}}}{r} = \frac{v_{\text{zewnętrznego koła}}}{r + \Delta r}\\
                \frac{v_\text{wewnęrznego koła}}{v_{\text{zewnętrznego koła}}} = \frac{r}{r + \Delta r}
            \end{gather}

            Aby policzyć stosunek prędkości silników, należy wyznaczyć promień skrętu.
            Do tego celu, można wykorzystać znane wartości i równanie \ref{eq:turning_radius}:
            \begin{gather}
                \tan \left(90 - \gamma\right) = \frac{l}{r}\\
                r(\gamma) = \frac{l}{\tan(90-\gamma)}
                \label{eq:turning_radius}
            \end{gather}
%
            gdzie:
            \begin{itemize}
                \item $l = 155$ -- długość między osiami samochodu,
                \item $\Delta r = 125$ -- odległość między kołami w jednej osi,
                \item $\gamma \in <60^\circ \div 120^\circ>$ -- kąt skrętu kół, ustawiany przez algorytm nawigacji lub użytkownika.
            \end{itemize}

        A zatem procentową różnicę szybkości w funkcji kąta można wyrazić jako:
        \begin{gather}
            \frac{v_{\text{prawe koła}}}{v_{\text{lewe koła}}} = 1 + \frac{\Delta r}{r} = 1 + \Delta r \cdot \frac{\tan(90 - \gamma)}{l}
            \label{eq:differential}
        \end{gather}

        Po zastosowaniu przedstawionego równania \eqref{eq:differential} w automatyce regulującej moc silników, udało się uzyskać powtarzalne wyniki podczas wykonywania tego samego manewru.

        \subsubsection{Nierównomierność skrętu}
        \label{subsec:nierownomiernosc_skretu}
            W trakcie testów okazało się, że pojazd nie skręca równomiernie w obie strony.
%
            Podczas ruchu w prawo, na łuku o długości $s = 500mm$, samochód zakreślał kąt około $70^\circ$.
            Natomiast na tym samym odcinku, ale w lewo wyznaczany kąt to około $50^\circ$.

            Wymusiło to ustawienie offsetu, przesuwającego środek osi.
            Jego wartość została otrzymana eksperymentalnie i była równa $-6^\circ$.
            Po wprowadzeniu poprawki uzyskany łuk podczas skręcania w obu kierunkach wynosił około $60^\circ$.

    Dzięki wszystkim wyżej wymienionym zabiegom udało się uzyskać powtarzalne wyniki, zarówno w czasie jazdy prosto, cofania się oraz skręcania.
    Podane działania są niezbędne, jeśli budowany robot ma być sterowany autonomicznie.

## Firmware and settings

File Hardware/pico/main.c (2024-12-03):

#include <pico/stdlib.h>
#include <pico/stdio.h>
#include <pico/multicore.h>
#include <pico/util/queue.h>
#include <hardware/timer.h>
#include <math.h>


#include "my_gpio.h"
#include "utilites.h"
#include "i2c.h"

#include "udp.h"
#include "tof.h"
#include "mpu6050.h"
#include "compass.h"
#include "servo.h"
#include "motor.h"
#include "counter.h"
#include "ir.h"
#include "eeprom.h"
#include "flash.h"

#define ANGLE_DT            50
static float old_angle    = 0;
Servo_t servo;
float angleError   = 0;
static int reachAngle = 0;
repeating_timer_t angle_timer;
static PID_t turning_pid;

static ToF_t ToF_left, ToF_center, ToF_right;

#define FORWARD_DIRECTION  0
#define BACKWARD_DIRECTION 1
static bool direction = FORWARD_DIRECTION;



bool angle_update(repeating_timer_t *timer){
    axis_ft_t acc, gyro;
    const float dt = ANGLE_DT/1000.f;

    int status = MPU6050_readData(&acc, &gyro);
    if (status != PICO_OK){
        return true;
    }

    axis_ft_t angles = {0, 0, 0};
    MPU6050_removeGravity(&acc);
    MPU6050_angleWithGyro(&angles, &gyro, &acc, dt);
    if (fabsf(angles.z) >= 0.005f){
        angleError += angles.z;
    }


    if (servo.angle == 90 && Motor_state() == MOTOR_RUN){
        int error = angleError;
        if (direction == BACKWARD_DIRECTION){
            error = -error;
        } 

        int pid = PID_update(&turning_pid, error, dt);
        Servo_setAngle(&servo, servo.angle + pid);
    }
    if (reachAngle != 0){
        if (abs(angleError) >= abs(reachAngle)){
            Motor_stop();
            reachAngle = 0;
        }
    }
    return true;
}


void Front_servo_Init(Servo_t * servo){
    servo->GPIO = GPIO_FRONT_SERVO;
    servo->min = FRONT_SERVO_MIN;
    servo->max = FRONT_SERVO_MAX;
    servo->offset = FRONT_SERVO_OFFSET;
    Servo_init(servo, false);
    Servo_setAngle(servo, 90);
    servo->angle = 90;
}

void Init_motion(){
    servo.angle = 90;

#if MOTOR_DIFFERENTIAL
    Motor_setDifferential(servo.angle);
#endif
    Servo_start(&servo);
    Motor_forwardDistance(1);

    Motor_setSpeed(MOTOR_HALF_SPEED);
}


void myReadLine(){
    char line[128] = {0};
    char c = 0;
    uint index = 0;
    static float speed = 0.5;


    while (true){
        c = 0;
        index = 0;

        while (!UDP_read(line)){
            sleep_ms(10);
        }

        float read = findFloat(line, 128);
        
        switch (line[0]){
            case 's':{
                if (strlen(line) != 1){
                    speed = read;
                    uint16_t data = read * MOTOR_FULL_SPEED;
                    Motor_setSpeed(data);
                    UDP_send("Speed set to: %hu\n", data);
                }
                UDP_send("Speed: %2.2f\n", speed);
            } break;

            case 'i':{
                UDP_send("Impulse: %6i, %6i\n", Counter_getCount(MOTOR_ENCODER_LEFT_UP), Counter_getCount(MOTOR_ENCODER_RIGHT_UP));
                UDP_send("Distance: %6.2f, %6.2f\n", pulseToDistance(Counter_getCount(MOTOR_ENCODER_LEFT_UP)), pulseToDistance(Counter_getCount(MOTOR_ENCODER_RIGHT_UP)));
                const PID_t *pid = Motor_getPID();
                UDP_send("PID: %6.2f", pid->P + pid->I + pid->D);
                UDP_send("Angle: %6.2f\n", angleError);
            } break;

            case 'f': {
                angleError = 0;
                direction = FORWARD_DIRECTION;
                IR_disable();
                if (strlen(line) > 1){
                    Motor_setDistance(read);
                    UDP_send("Distance set to: %6.2fmm\n", read);
                }   
                Servo_start(&servo);
                sleep_ms(250);
                if (line[1] == 'l') {
                    Motor_setSpeedLeft(MOTOR_FULL_SPEED * speed);
                    Motor_setSpeedRight(0);
                    Motor_forwardLeft();
                } else if (line[1] == 'r') {
                    Motor_setSpeedRight(MOTOR_FULL_SPEED * speed);
                    Motor_setSpeedLeft(0);
                    Motor_forwardRight();
                } else {
                    Motor_setSpeed(MOTOR_FULL_SPEED * speed);
                    Motor_forward();
                }
                UDP_send("Motor forward\n");
            } break;

            case 'b': {
                angleError = 0;
                direction = BACKWARD_DIRECTION;
                IR_enabled();
                if (strlen(line) > 1){
                    Motor_setDistance(read);
                    UDP_send("Distance set to: %6.2fmm\n", read);
                }   
                Servo_start(&servo);
                sleep_ms(250);
                if (line[1] == 'l') {
                    Motor_backwardLeft();
                } else if (line[1] == 'r') {
                    Motor_setSpeedRight(MOTOR_FULL_SPEED * speed);
                    Motor_setSpeedLeft(0);
                    Motor_backwardRight();
                } else {
                    Motor_setSpeed(MOTOR_FULL_SPEED * speed);
                    Motor_backward();
                }
                UDP_send("Motor backward\n");
            } break;

            case 'd': {
                Motor_setDistance(read);
                UDP_send("Distance set to: %6.2fmm\n", read);
                // stop = false;
            }break;

            case 'r':{
                if (line[1] == 'o'){
                    if (strlen(line) > 2){
                        servo.offset = read;
                    }
                    UDP_send("Servo offset: %i\n", servo.offset);
                    break;
                }

                if (line[1] == 's'){
                    if (servo.run){
                        Servo_stop(&servo);
                        UDP_send("Servo stop\n");
                    } else {
                        Servo_start(&servo);
                        UDP_send("Servo run\n");
                    }
                }

                if (strlen(line) > 2){
                    servo.angle = read;
                    Servo_overshoot(&servo, servo.angle);
                    #if MOTOR_DIFFERENTIAL
                        Motor_setDifferential(servo.angle);
                    #endif
                    angleError = 0;
                    PID_reset(&turning_pid);
                }
                UDP_send("Servo angle %i\n", servo.angle);
            } break;

            case 'c':{
                if (line[1] == 'r'){
                    cancel_repeating_timer(&angle_timer);

                    UDP_send("Reset bus\n");
                    I2C_resetBus();
                    UDP_send("Bus init\n");

                    add_repeating_timer_ms(ANGLE_DT, angle_update, NULL, &angle_timer);
                }

            #if COMPASS_AUTO_CALIBRATION_PROCESS
                cancel_repeating_timer(&angle_timer);
                axis_t offset = COMPASS_applyCalibration();
                add_repeating_timer_ms(ANGLE_DT, angle_update, NULL, &angle_timer);
                UDP_send("Calibration parameter: %i, %i, %i\n", offset.x, offset.y, offset.z);
            #endif
                axis_t magneto;
                COMPASS_read(&magneto);
                float azimuth = COMPASS_getAzimuth(magneto.x, magneto.y);
                UDP_send("Magnetometr: %6i, %6i, %6i\n", magneto.x, magneto.y, magneto.z);
                UDP_send("Azimuth: %6.2f\n", azimuth);
                UDP_send("Move angle: %.2f\n", angleError);
            } break;

            case 'm':{
                if (line[1] == 'r'){
                    int error = ToF_Init(&ToF_left, &ToF_center, &ToF_right);
                    if(error & 0b001)     UDP_send("ToF left error\n");
                    if(error & 0b010)     UDP_send("ToF center error\n");
                    if(error & 0b100)     UDP_send("ToF right error\n");
                }

                int left = ToF_oneShotMeasure(&ToF_left);
                int center = ToF_oneShotMeasure(&ToF_center);
                int right = ToF_oneShotMeasure(&ToF_right);
                UDP_send("M %i %i %i\n", left, center, right);
            } break;

            case '[':{
                int devs[20];
                int numOfDev = I2C_scan(i2c1, devs);
                UDP_send("I2C devices: %d\n", numOfDev);
                for (int i = 0; i < numOfDev; i++){
                    UDP_send("\tAddress: 0x%02X\n", devs[i]);
                }
            } break;

            default:
                break;
        }

        if (strlen(line) == 0){
            return;
        }
    }
}

void sendStatistic(){
    uint count_left, count_right;
    float distance_left, distance_right;
    uint16_t PWM_left, PWM_right;
    uint time = time_us_32();
    uint endTime = 0;
    const PID_t *motorPID = Motor_getPID();

    while (time > endTime){
        count_left = Counter_getCount(MOTOR_ENCODER_LEFT_UP);
        count_right = Counter_getCount(MOTOR_ENCODER_RIGHT_UP);
        distance_left = pulseToDistance(count_left);
        distance_right = pulseToDistance(count_right);
        PWM_left = Motor_getSpeed(MOTOR_LEFT_PWM);
        PWM_right = Motor_getSpeed(MOTOR_RIGHT_PWM);

        time = time_us_32();
        UDP_send(
            "Time: %10uus, Count: %6u, %6u, distance: %6.2f, %6.2f, Angle: %6.2f, PWM: %6hu, %6hu, PID: %6.2f\n",
            time, count_left, count_right, distance_left, distance_right, angleError, PWM_left, PWM_right, motorPID->P + motorPID->I + motorPID->D
        );
        sleep_ms(100);
        
        if (Motor_state() == MOTOR_STOP){
            endTime = make_timeout_time_ms(2000);
        }
    }
}


int main(){
    stdio_init_all();
    multicore_launch_core1(UDP_main);
    IR_init();

    I2C_Init();
    I2C_resetBus();
    ToF_Init(&ToF_left, &ToF_center, &ToF_right);
    MPU6050_Init();
    COMPASS_Init();

    PID_init(&turning_pid, 0.5f, 1.f, 0.5f);

    Motor_init();
    Front_servo_Init(&servo);
    // Counter_disabledIRQ(MOTOR_ENCODER_LEFT_UP);
    // Counter_disabledIRQ(MOTOR_ENCODER_RIGHT_UP);


    float speed = 0.5f;
    float _time;
    add_repeating_timer_ms(ANGLE_DT, angle_update, NULL, &angle_timer);
    sleep_ms(ANGLE_DT * 3);
    angleError = 0;

    Init_motion();
    Servo_stop(&servo);

    while(1){
        myReadLine();
        sendStatistic();
    }

    return 0;
}

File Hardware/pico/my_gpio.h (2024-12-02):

#ifndef __MY_GPIO_H__
#define __MY_GPIO_H__

#include <hardware/i2c.h>
#include <hardware/spi.h>

#define CAR_WIDTH                       (135)
#define CAR_LENGTH                      (155)

#define NC                              (-1)


#define GPIO_SPI_CHANNEL                spi0
#define GPIO_SPI_CLK                    2
#define GPIO_SPI_TX                     3
#define GPIO_SPI_RX                     4

#define GPIO_FLASH_CS                   5


#define GPIO_MOTOR_RIGHT_PIN_FORWARD    9
#define GPIO_MOTOR_RIGHT_PIN_BACKWARD   8
#define GPIO_MOTOR_ENCODER_RIGHT_UP     21
#define GPIO_MOTOR_ENCODER_RIGHT_DOWN   NC

#define GPIO_MOTOR_LEFT_PIN_FORWARD     7
#define GPIO_MOTOR_LEFT_PIN_BACKWARD    6
#define GPIO_MOTOR_ENCODER_LEFT_UP      19
#define GPIO_MOTOR_ENCODER_LEFT_DOWN    NC

#define GPIO_MOTOR_RIGHT_PWM            16
#define GPIO_MOTOR_LEFT_PWM             17

#define GPIO_FRONT_SERVO                13
#define FRONT_SERVO_MIN                 60
#define FRONT_SERVO_MAX                 120
#define FRONT_SERVO_OFFSET              -6

#define GPIO_RIGHT_BACK_SENSOR          27
#define GPIO_LEFT_BACK_SENSOR           26


#define GPIO_I2C_CHANNEL                i2c1
#define GPIO_I2C_SDA                    14
#define GPIO_I2C_SCL                    15

#define GPIO_ToF_RIGHT_CONTROL_PIN      11
#define GPIO_ToF_CENTER_CONTROL_PIN     12
#define GPIO_ToF_LEFT_CONTROL_PIN       10

#define GPIO_COMPASS_INT_PIN            22
#define GPIO_MPU6050_INT_PIN            28


#endif

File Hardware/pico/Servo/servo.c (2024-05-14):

#include "servo.h"
#include <stdio.h>
#include <hardware/clocks.h>


// Servo need 50Hz, f_sys = 125HMz
#define PRESCALER   100
#define TOP       24999

#define LEVEL_MIN 600
#define LEVEL_MAX 3200

#define ADC_MAX 3850
#define ADC_MIN 260


void Servo_init(Servo_t *servo){
    // static uint PWM_STATE = 0;
    static uint ADC_STATE = 0;
    servo->start = true;

    if (servo->step == 0)
        servo->step = 1;

    // PWM INIT
    gpio_set_function(servo->GPIO, GPIO_FUNC_PWM);
    uint slice_num = pwm_gpio_to_slice_num(servo->GPIO);

    pwm_config config = pwm_get_default_config();

    config.div = PRESCALER << PWM_CH0_DIV_INT_LSB;
    config.top = TOP;

    pwm_init(slice_num, &config, true);

    if (servo->ADC_PIN >= 26 && servo->ADC_PIN <= 28){
        adc_gpio_init(servo->ADC_PIN);
        servo->current_angle = Servo_readAngle(servo);
    } else {
        servo->current_angle = 0;
    }
}


void Servo_setAngle(Servo_t *servo, uint angle){
    if (angle > servo->max){angle = servo->max;} else
    if (angle < servo->min){angle = servo->min;}

    uint16_t level = LEVEL_MIN + angle * ((LEVEL_MAX - LEVEL_MIN) / 180);
    servo->current_angle = angle;
    pwm_set_gpio_level(servo->GPIO, level);
}


int Servo_readAngle(Servo_t *servo){
    adc_select_input(servo->ADC_PIN - 26);
    int value = adc_read();

    value = ((value - ADC_MIN) * 180) / (ADC_MAX - ADC_MIN);
    if (servo->flipRead)
        value = 180 - value;
    return value;
}


void Servo_goto(Servo_t *servo){
    if (!servo->start) return;
    
    uint small_step = servo->step;

    if (servo->current_angle != servo->angle){
        if (abs(servo->angle - servo->current_angle) < servo->step){
            small_step = abs(servo->angle - servo->current_angle);
        }
        if(servo->current_angle > servo->angle){
            servo->current_angle -= small_step;
        } else {
            servo->current_angle += small_step;
        }

        Servo_setAngle(servo, servo->current_angle);
    }
}

void Servo_start(Servo_t *servo){
    servo->start = true;
    servo->angle = servo->backUp;
    Servo_setAngle(servo, servo->angle);
    uint slice = pwm_gpio_to_slice_num(servo->GPIO);
    pwm_set_enabled(slice, true);
}

void Servo_stop(Servo_t *servo){
    servo->start = false;
    uint slice = pwm_gpio_to_slice_num(servo->GPIO);
    pwm_set_enabled(slice, false);
}

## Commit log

2024-03-16 VL53L0X ToF sensor works
2024-05-05 MPU6050 gyro, temp work. WiP acc calibration
2024-05-05 Servo lib
2024-05-06 Comment acc calibration - dont work
2024-05-09 Make model to calibrate MPU6050
    [Podstawka_do_kalibraci_MPU6050.FCStd]
2024-05-12 Gyro calibration work
2024-05-14 I2C scan sel channel
2024-05-14 Change gyro cali data from define to const type
2024-07-21 Create models for car
    [CalibrationHolder_MPU6050.FCStd, CalibrationHolder_MPU6050_longLeg.FCStd, FrontWheelHolder.FCStd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]
2024-12-02 Color printf, test main
2024-12-02 Fix bug with wrong type in path finding
    [main.c, utility.h]
2024-12-02 Add counter to motor
2024-12-02 Add I2C from my_gpio.h and set ToF on init as single shot
2024-12-02 Add servo reach angle function, corrent max angle
2024-12-02 Compass calibration process by find and remove offset
2024-12-02 Add masked write to i2c
2024-12-02 Distance set on each motor
2024-12-02 Add FIFO, and calculate angles with gyro and acc
2024-12-02 Motor control speed and equal speed on bouth motor
2024-12-02 UDP mirror printing, to main and mirror port
2024-12-02 UDP mirror printing fix
2024-12-02 PICO external memory lib
2024-12-02 Return status of I2C transaction
2024-12-02 Return current errorAngle 250ms post stop
2024-12-02 Turn on and off compass calibration code
2024-12-02 Servo overshoot
2024-12-02 Motor add read status
2024-12-02 Make docs
    [PID_speed_10.csv, angles.csv, distance_no_PID_speed_50.csv]
2024-12-02 I2C with timeout and ignore IRQ
2024-12-02 Motor differential, control signle motor, fix calculate distance and pulse
2024-12-02 Cleaning code, fix some bug, add comments and add test
    [main.c, my_gpio.h]
2024-12-02 Fix typo with file name
    [data.csv]
2024-12-02 Fix bug with throw out window and turnging
    [main.c, utility.h]
2024-12-03 Fix bug with differential
    [speed.csv]
2024-12-27 Correction chapter 1-4
    [speed.csv]
